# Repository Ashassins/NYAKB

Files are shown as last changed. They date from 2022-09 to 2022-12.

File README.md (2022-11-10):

# NYAKB: Not Your Average Keyboard
ECE 477 Project

NYAKB is a multimedia keyboard with hot swappable modules to enable flexibility for the users by allowing them to select the right keyboard layout for the task at hand. The product features a base keyboard with a familiar form factor, as well as modules which can be added and removed with a standard hot plug connector without interrupting the functionality of the rest of the keyboard. We will be making a display module and in the future other modules such as macropads, numpads, or rotary encoders could be added using the same connector to extend the functionality of the keyboard.

Project Website: https://engineering.purdue.edu/477grp3/

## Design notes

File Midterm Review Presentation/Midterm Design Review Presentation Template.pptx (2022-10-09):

## ECE477 Midterm Design Review: Team 3

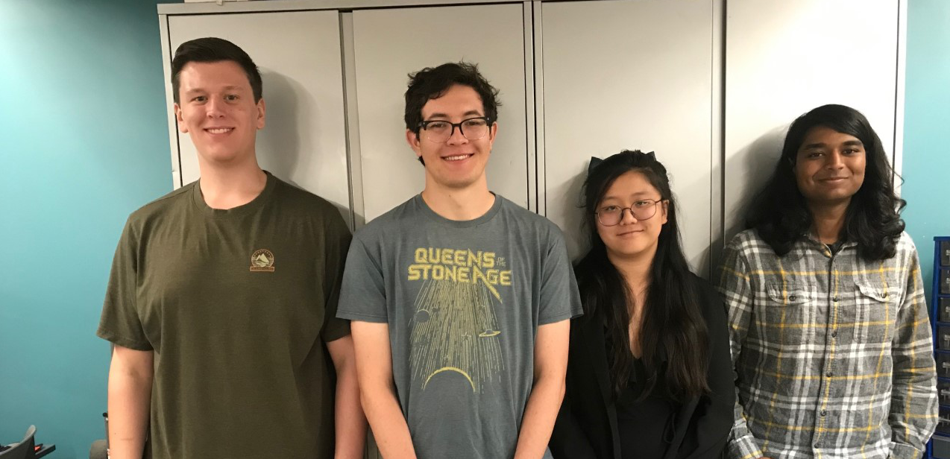
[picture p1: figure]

<Add team picture or relevant project picture here>

## Outline

- Project Overview
- Major Components
- Block Diagram
- Packaging Design
- Electrical Schematic
- PCB Layout
- Prototyping Progress
- Software Development Status
- Project Timeline
- Questions

## Project Overview

- Not your average Keyboard (NYAKB)

- NYAKB is a newcomer in the growing mechanical keyboard community that includes a high quality, phone sized LCD screen that will display various information, and can interact with the keyboard itself. The module will be detachable. Current keyboards on the market don't have the unique display functionality NYAKB has.

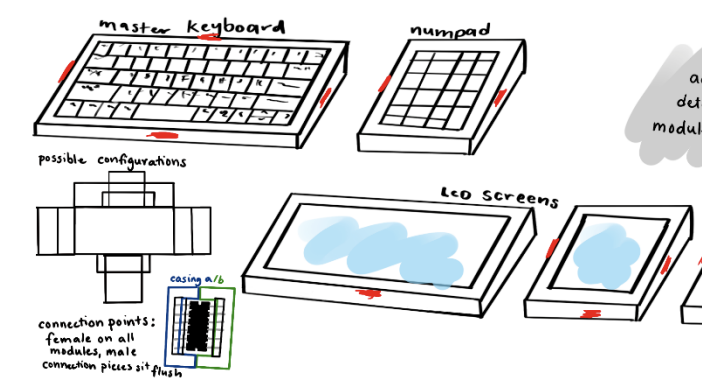
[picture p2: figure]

## PSSCs

1. PSSC #1 (Hardware): An ability to have a key switch matrix for the various typing keys on a keyboard that can be scanned and debounced for clean inputs by the microcontroller on the main keyboard module.
2. PSSC #2 (Hardware): An ability to drive an LCD display via SPI.
3. PSSC #3 (Hardware): An ability to step down 5V USB input power to 3.3V for the main keyboard MCU and display module MCU/display.
4. PSSC #4 (Hardware): An ability to have the main keyboard MCU serve as master and communicate to submodule MCU as slave over I2C.
5. PSSC #5 (Hardware): An ability to communicate key presses from the user to the Host PC over a USB connection.

## Major Components

- SUBTITLE

- Choose the major (electrical) components being utilized by your design. For each component, provide a brief description of what it is, relevant specifications, and what it will do. Examples of major components include the microcontroller, motors, wireless interfaces, power converters and regulators. Examples of relevant specifications include operating speed (uC), number of I/O (uC), stall current (motors), operating voltage, and expected current consumption

## Major Components

- Power Regulation

- Buck Converter: TPS563231DRLT
- Specs:
  - Input range 4.5V-17V
  - Output 3.3V
  - Max Current 3A
- Usage:
  - This will be used to step down USB 5V input to 3.3V that will power the main keyboard (stm32f4) as well as submodules via the hotplug connection

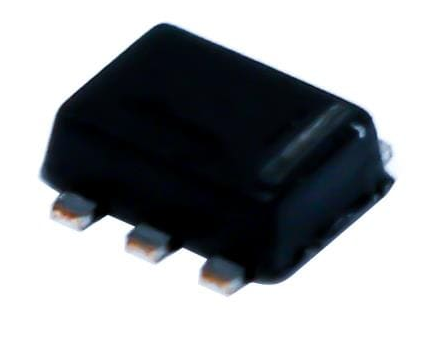
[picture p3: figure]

## Major Components

- Power Regulation

- Voltage Regulator: [Insert Name]
- Specs:
  - sdf
- Usage:
  - sdf

## Major Components

- Microcontrollers

- Main Keyboard MCU: STM32F407VGT6
- Specs:
  - USB FS Controller
  - I2C
  - GPIO
- Usage:
  - This MCU will be used to communicate with the host PC over USB and to submodules over I2C. It will also scan the key matrix with GPIO

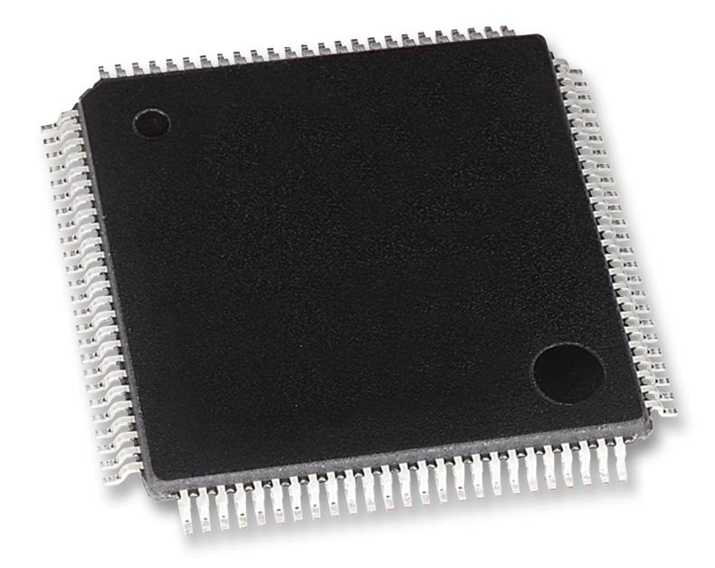
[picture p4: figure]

## Major Components

- Microcontrollers

- Main Keyboard MCU: STM32F091RCT6
- Specs:
  - I2C
  - SPI
- Usage:
  - This MCU will be used to communicate with the SPI TFT LCD display to draw info and to the main keyboard over I2C over the hotplug connector.

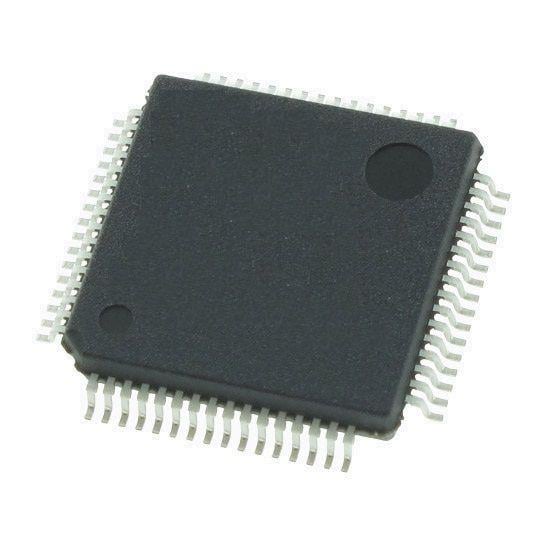
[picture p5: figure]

## Block Diagram

- Include one or more images of your system block diagram here. Block diagrams should include all relevant major parts and systems, bus widths, and interface types.

## Packaging Design

- Main Keyboard Original Design

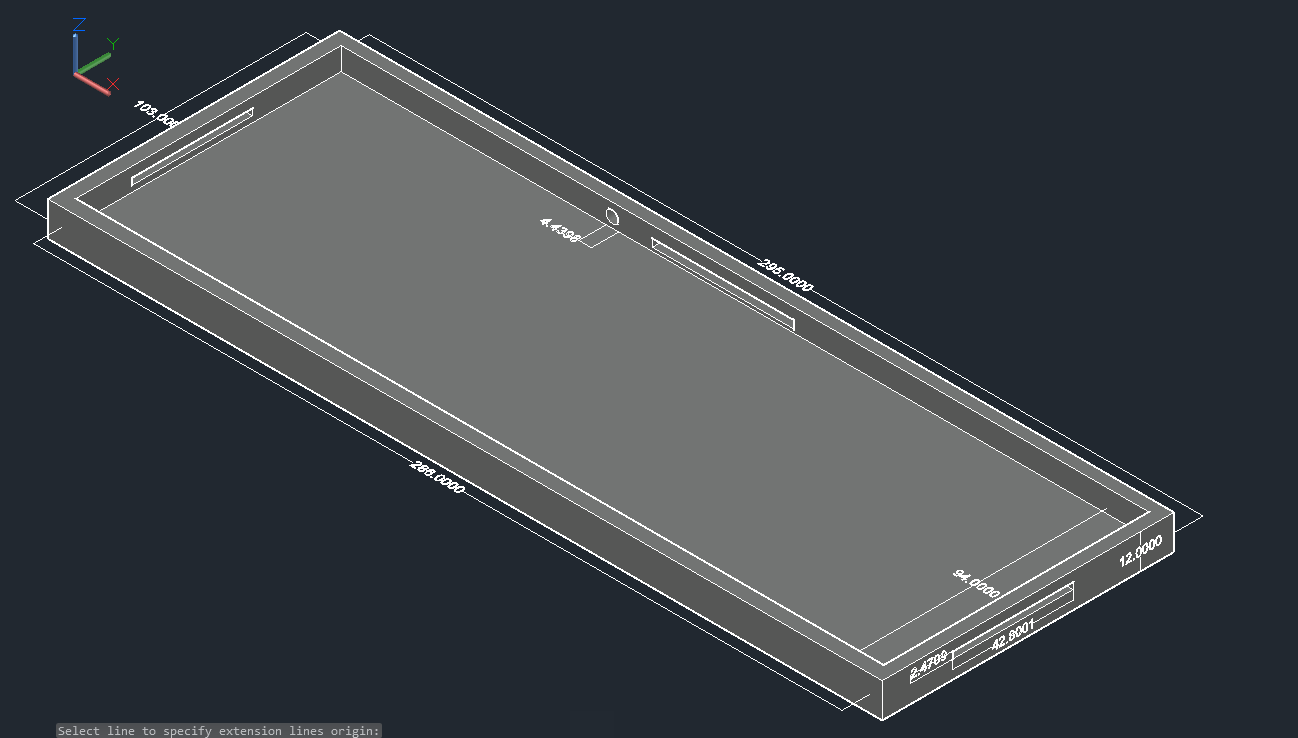
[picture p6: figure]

- Outer layer 295x103x12 mm
- Inner layer 286x94x8 mm
- 3 access points to allow it to connect to other modules, and a point of access to connect to the USB port.
- Keyboard has evolved, but the packaging design will remain fairly similar

## Packaging Design

- Peripheral Module

- Include one or more images of your packaging design here. Include relevant dimensions and how you are planning to manufacture your product packaging.
- We plan to use laser cut acrylic sheets to mount both keyboard modules

## Electrical Schematic

- Include one or more views of your electrical schematic here. If necessary, break up this section into multiple slides detailing various subsystems which are easily viewable (Hint: a zoomed out view of a large electrical schematic in which nothing can be read will not be helpful for the design review). Your schematics should be complete, organized, and readable.

## PCB Layout

- Include one or more views of your PCB Layout here. If necessary, break up this section into multiple slides detailing various subsystems which are easily viewable (Hint: a zoomed out view of a large electrical schematic in which nothing can be read will not be helpful for the design review). Your layout should be complete, organized, and readable.

## Prototyping Progress

- Describe your team’s prototyping progress here. For each of your project’s major components, what has been tested? What is known to work? What still needs to be tested, and what still needs to be proven to work?

## Software Development Status

- In this section, detail team progress with software development. List out the major modules for your team’s software. For each module, detail its status (Not yet started / In development / In testing / Completed)
- Keyboard Scanning and Debouncing (In development)

## Project Timeline

- Provide a timeline (or GANTT chart, etc.), starting from the current week until the end of the semester, detailing work to be undertaken in completing your team’s project.

## 3D Printing

- Questions?

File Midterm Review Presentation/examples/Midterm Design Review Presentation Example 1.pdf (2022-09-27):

# ECE 477 DESIGN REVIEW TEAM 3 − SPRING

2015

Garrett
Bernichon

Bryan
Marquet

John
Skubic

Tim
Trippel

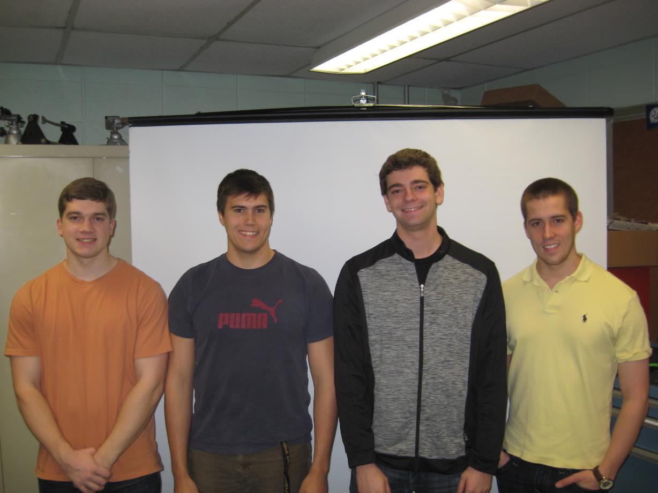
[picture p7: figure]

# OUTLINE

•Project overview

•Project-specific success criteria

•Block diagram

•Component selection rationale

•Schematic and theory of operation

•PCB layout

•Packaging design

•Software design/development status

•Project completion timeline

•Questions / discussion

# PROJECT OVERVIEW

•Stratus provides additional storage for mobile devices

•The storage is accessed from a Wi-Fi hotspot

•Data is stored on Stratus via a micro SD card

•System status is presented via a graphical display

•Stratus is powered by a lithium polymer battery chargeable by a USB cable

# PROJECT-SPECIFIC SUCCESS CRITERIA

•An ability to stream information from Stratus to an external device using Wi-Fi.

•An ability to charge and manage a battery system, and inform the microcontroller of remaining charge.

•An ability to read and write data to a SD card unit connected to Stratus.

•An ability to browse and select files to stream from Stratus via a mobile app.

•An ability to display information such as battery life, Wi-Fi connection status, and name of current file being accessed to the user via a graphics display connected to Stratus.

# BLOCK DIAGRAM

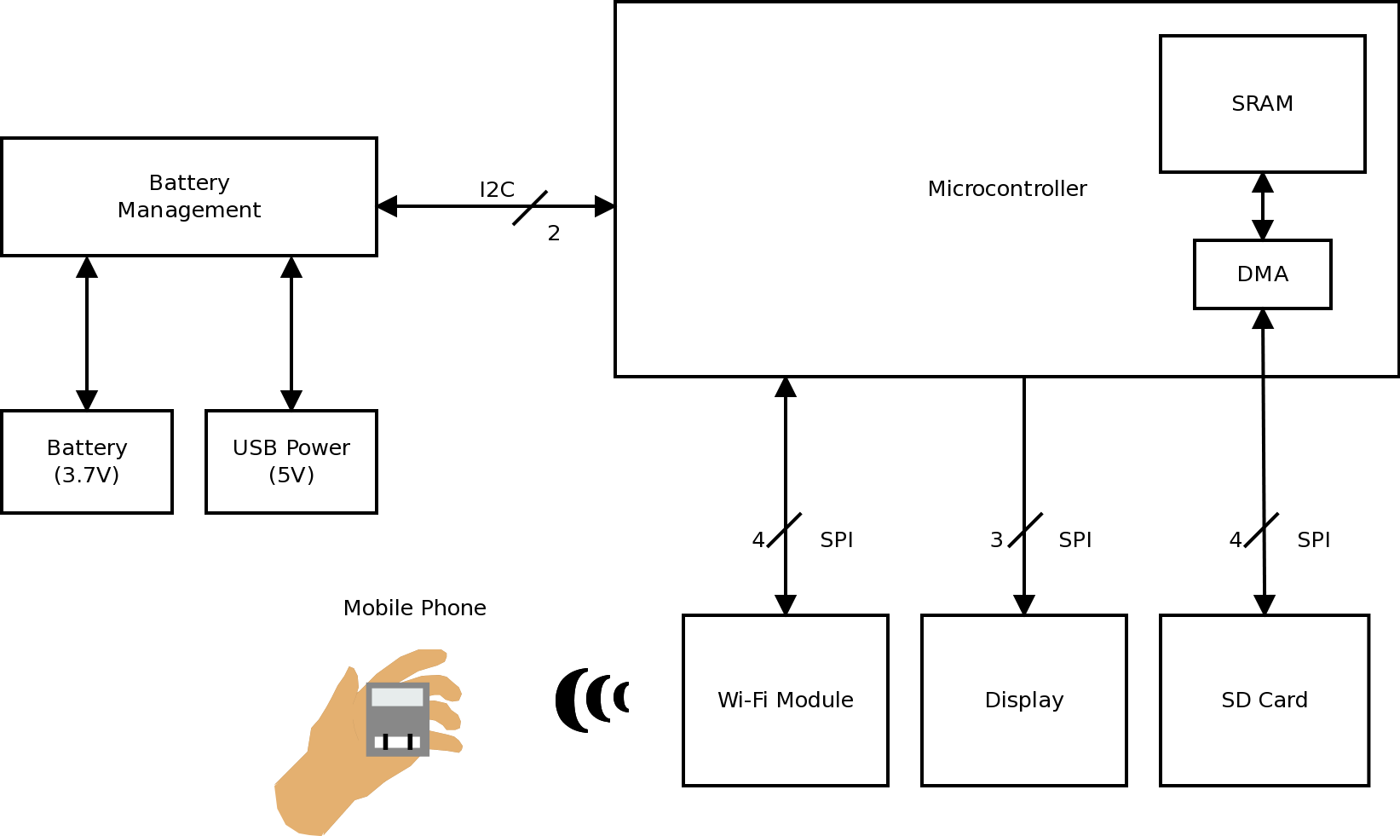
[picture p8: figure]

# COMPONENT SELECTION RATIONALE: MICROCONTROLLER

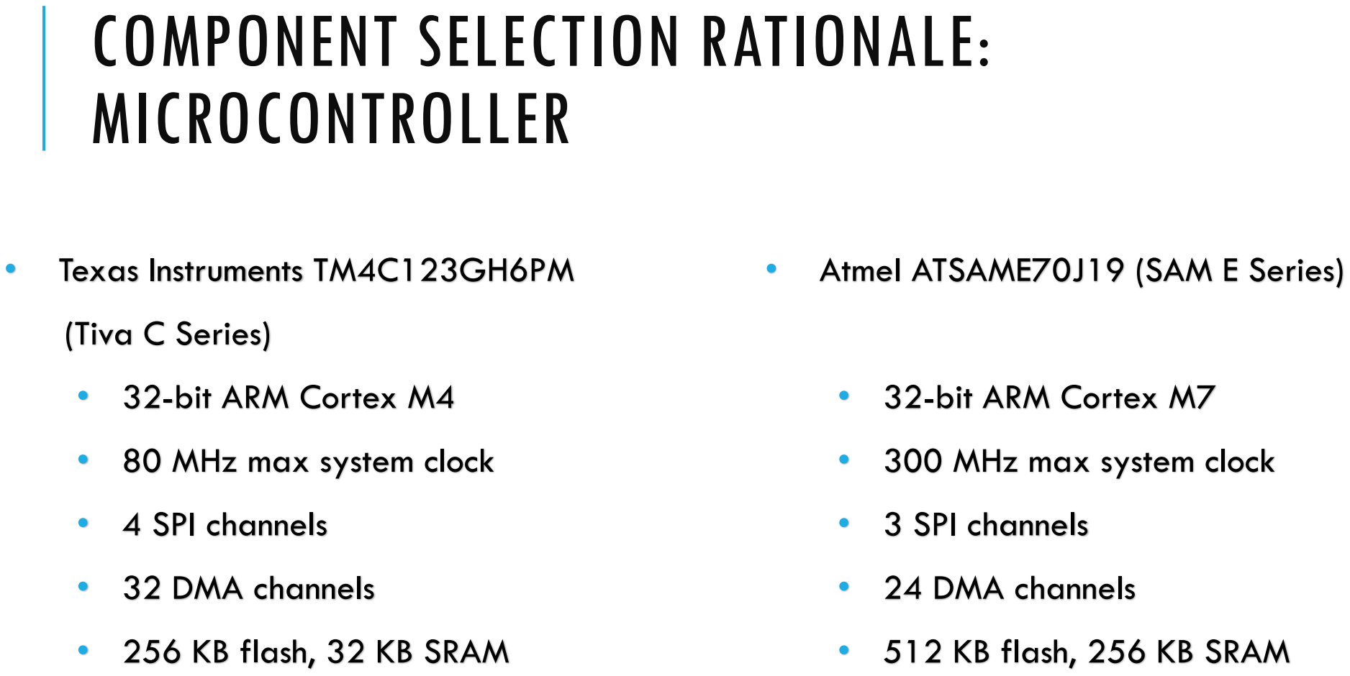
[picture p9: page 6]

- Texas Instruments TM4C123GH6PM

(Tiva C Series)

- 32-bit ARM Cortex M4
- 80 MHz max system clock
- 4 SPI channels
- 32 DMA channels
- 256 KB flash, 32 KB SRAM
- Atmel ATSAME70J19 (SAM E Series)
- 32-bit ARM Cortex M7
- 300 MHz max system clock
- 3 SPI channels
- 24 DMA channels
- 512 KB flash, 256 KB SRAM

# COMPONENT SELECTION RATIONALE: WI-FI VS. BLUETOOTH

### Wi-Fi

+ Higher throughput
+ More open
- Power Consumption
- Extra software for configuration as both an access-point or not

### Bluetooth

+ Low-power
- Low throughput

# COMPONENT SELECTION RATIONALE: WI-FI MODULE

TI CC3100

+ Creates a Wi-Fi hotspot
- Module has pins on bottom

TI CC3000

+ small module with antenna
- Can’t create a Wi-Fi hotspot

TI CC3200

+ Has built-in ARM processor + Creates Wi-Fi hotpot
- Requires an OS
- Not hand solderable

# COMPONENT SELECTION RATIONALE: DISPLAY

Sharp LS013B4DN04 LCD E-Paper hybrid

1.35” screen
+ Low power consumption
+ No external circuit needed
- More complex software

RePaper E-Paper display

1.3” screen
+ Low power consumption
+ Simple software interface
- Requires large external circuit
- Requires 3.3V and 5.0V

# COMPONENT SELECTION RATIONALE: BATTERY

Constraints:
- Maximum size, must fit inside packaging
- Minimum capacity, aiming for six hours of heavy usage (heavy = 370 mA approx.)

Decision:

- Polymer Lithium Ion Battery 2000 mAh

# SCHEMATIC/THEORY OF OPERATION : MICROCONTROLLER

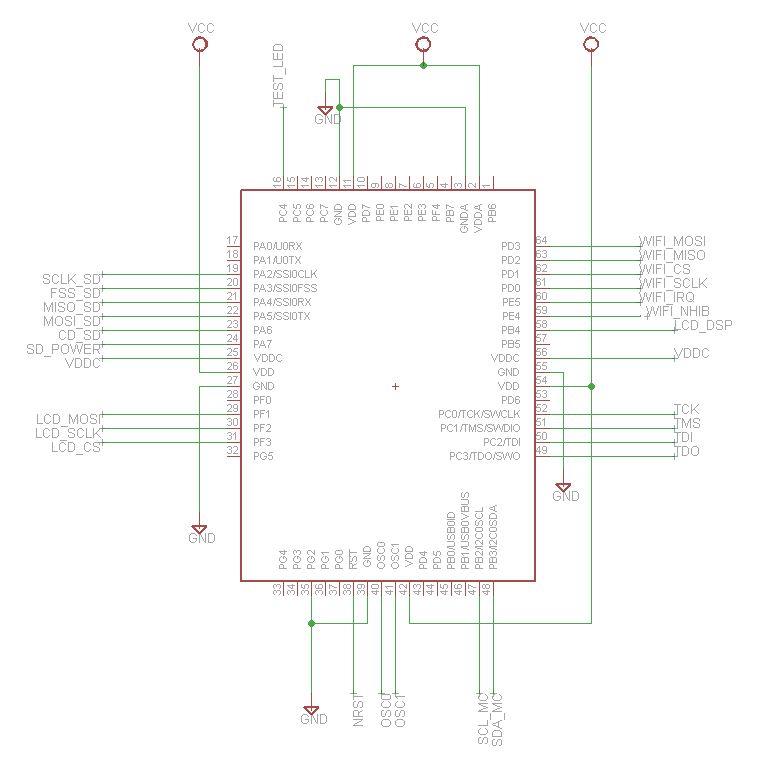
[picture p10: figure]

Microcontroller
- System Clock
- Internal PLL to achieve 40 MHz
- 16 MHz External (for boot-up)
- Serial connections
- Battery Monitor (I2C)
- SD Card (SPI)
- Wi-Fi module (SPI)
- LCD (SPI)

# SCHEMATIC/THEORY OF OPERATION : WI-FI

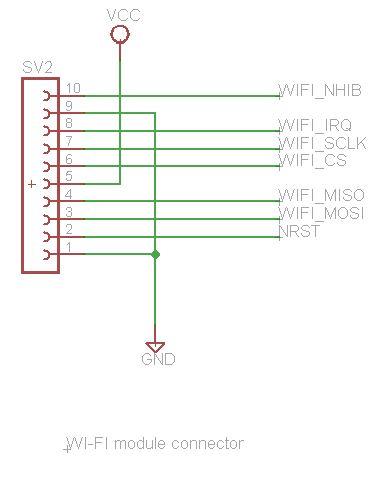
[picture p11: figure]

Wi-Fi Module
- External module
- 20 MHz max SPI CLK

Designing our own module
- Solderablility
- Antenna design

# SCHEMATIC/THEORY OF OPERATION : LCD

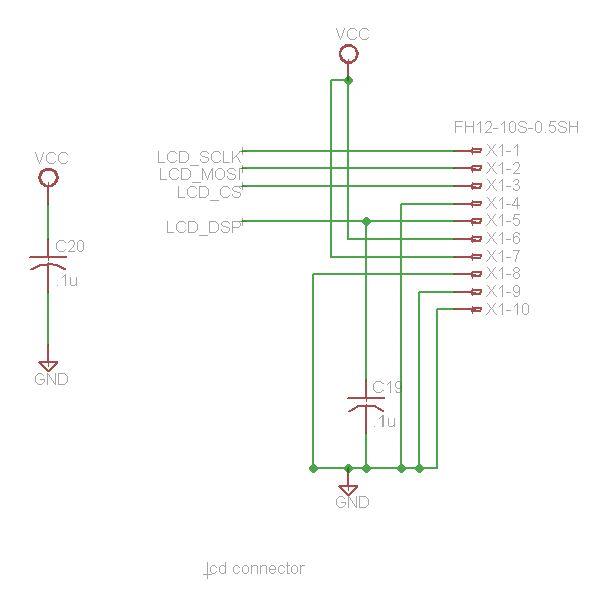
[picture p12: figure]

LCD/E-paper Hybrid Screen

•Interfaces with SPI at 1Mbps

•Setup so VCOM signal is set using SPI

# SCHEMATIC/THEORY OF OPERATION : SD CARD

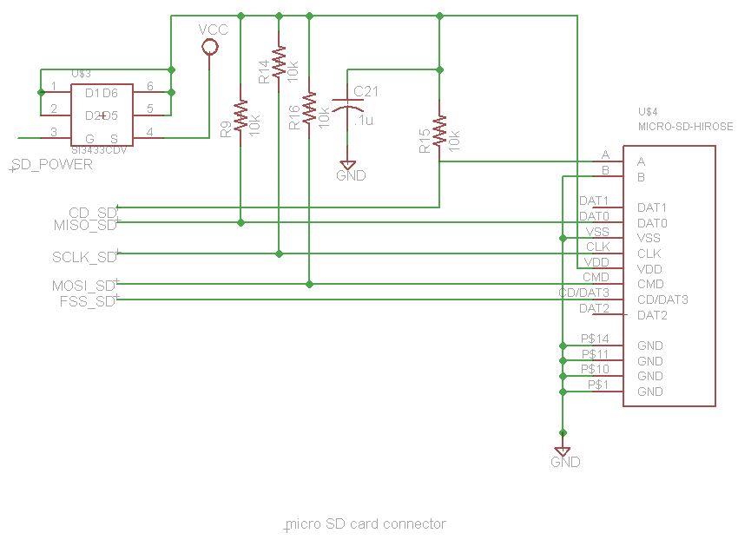
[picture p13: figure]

SD Card

•Interfaces with SPI at ~20-25 Mbps

•Pull-Up resistors for idle (Hi-Z) lines → SD requires idle to be high

•Power MOSFET for software control of hard-reset

•Chip-Detect signal

# SCHEMATIC/THEORY OF OPERATION: POWER

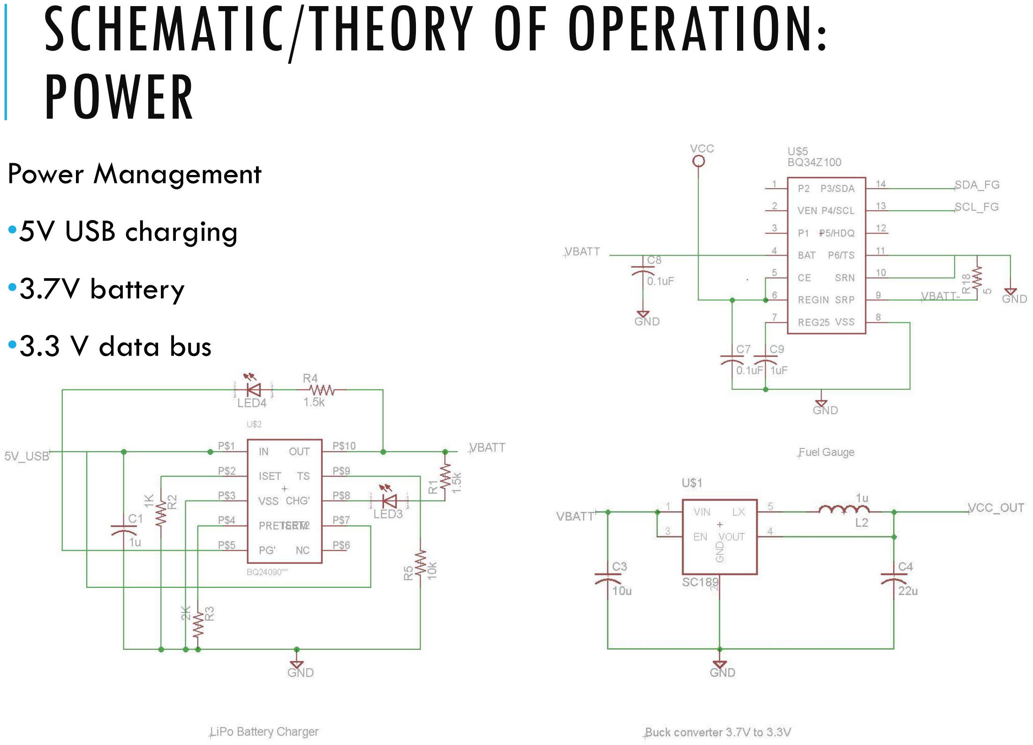
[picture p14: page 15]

Power Management

•5V USB charging

•3.7V battery

•3.3 V data bus

# PCB LAYOUT

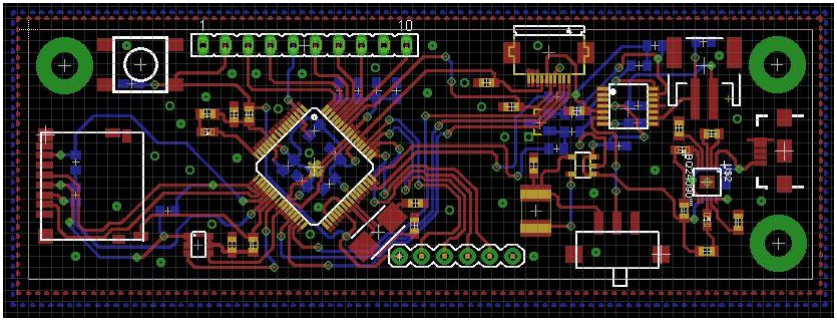
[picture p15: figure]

# PCB LAYOUT

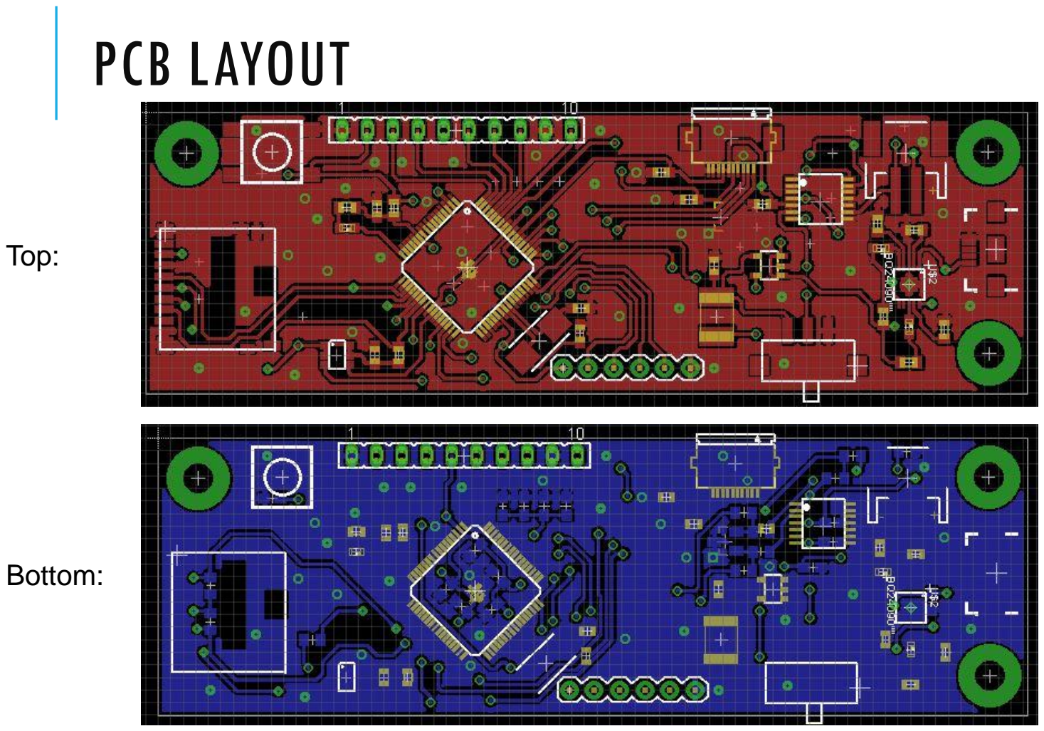
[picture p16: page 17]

Top:

Bottom:

# PCB LAYOUT

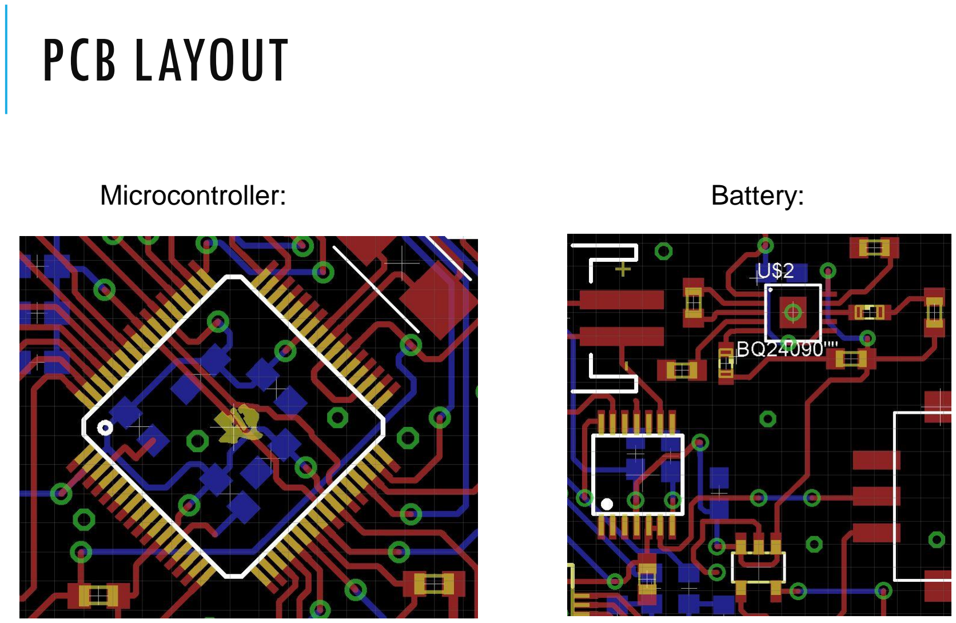
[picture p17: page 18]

Microcontroller: | Battery:

# PACKAGING DESIGN

•Dimensions: 90 x 57 x 13 (mm)

•Two 3D printed plastic pieces will be screwed together, one top and one bottom with sides

•Insulation will be added inside to aid in securing components.

•Battery Dimensions: 5.8 x 54 x 60 (mm)

•PCB Dimensions: 86 x 28 (mm)

# PACKAGING DESIGN

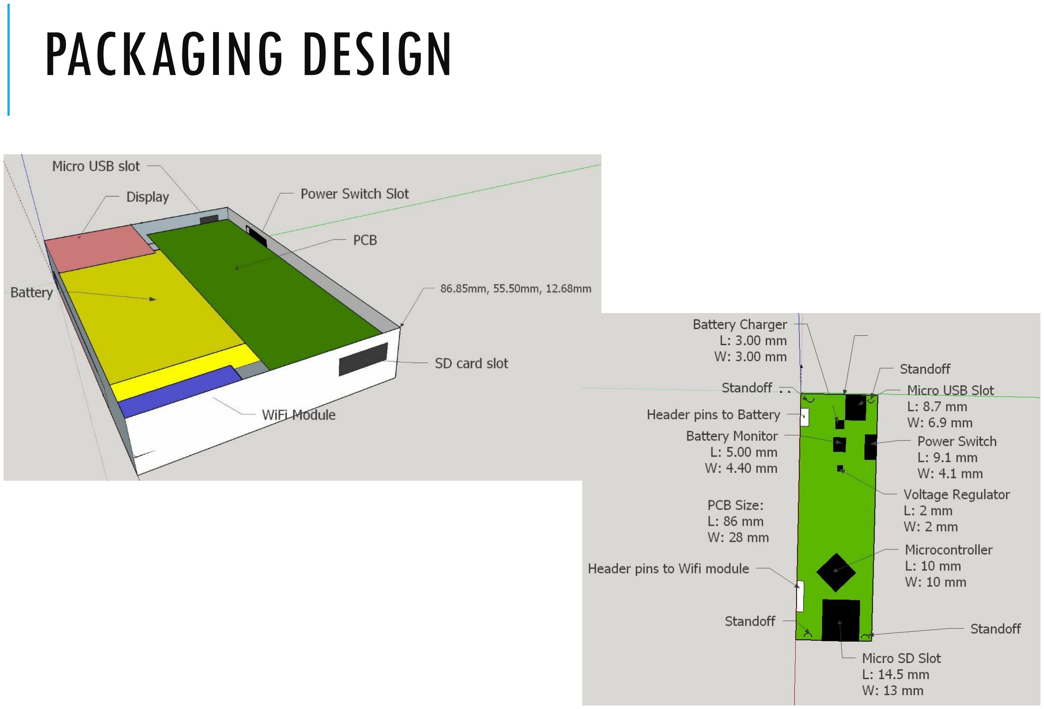
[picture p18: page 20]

# SOFTWARE DEVELOPMENT STATUS

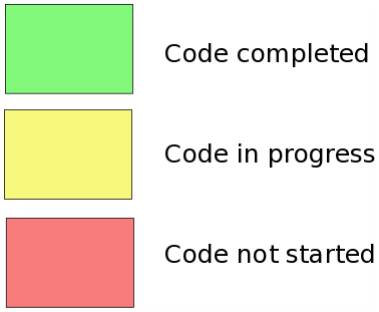
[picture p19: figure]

Embedded
- Embedded Initializations
- System Status Interrupts
- Wi-Fi Interface
- DMA Controller Interrupts
- Main Control Loop

iOS Development
- Using Python TCP server to act as Stratus
- Can request and receive music library
- Can request, receive, and play a song
- User Interface is 75% complete

# SOFTWARE DEVELOPMENT STATUS

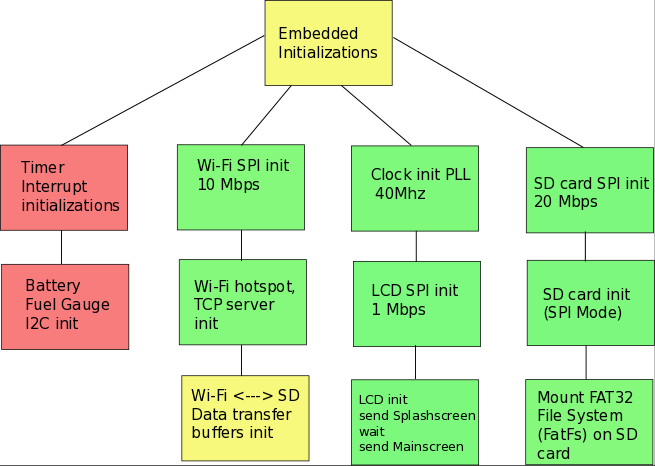
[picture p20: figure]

# SOFTWARE DEVELOPMENT STATUS

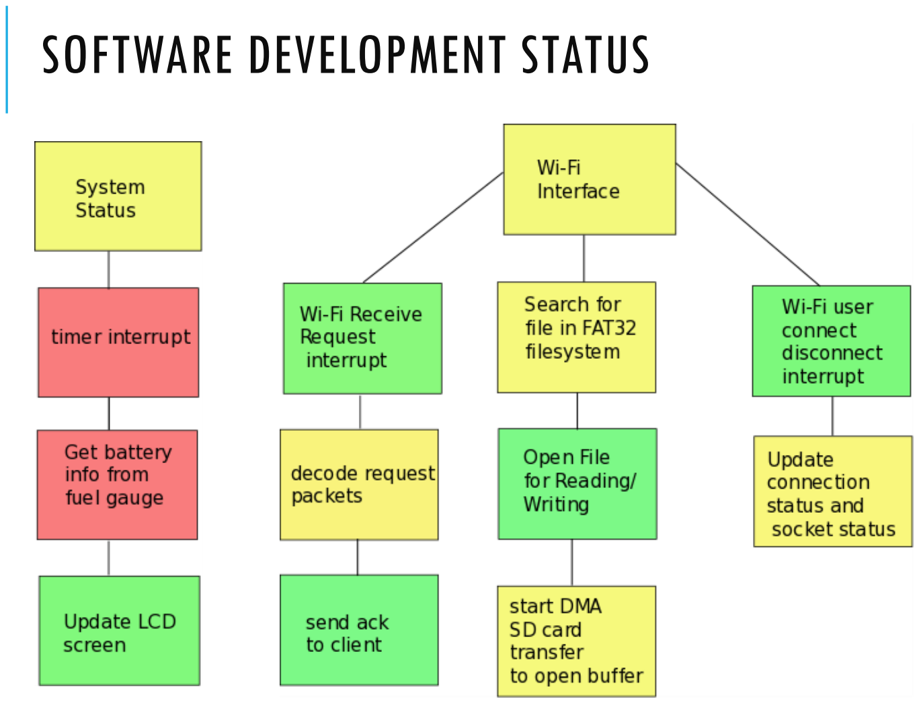
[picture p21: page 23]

# SOFTWARE DEVELOPMENT STATUS

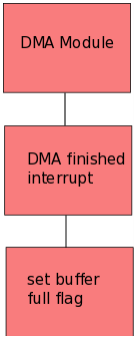
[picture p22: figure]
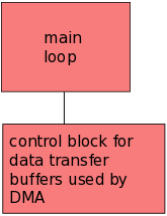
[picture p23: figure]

# SOFTWARE DEVELOPMENT STATUS

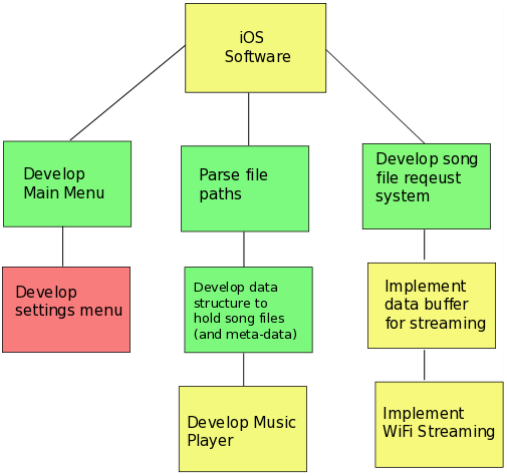
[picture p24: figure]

# PROJECT COMPLETION TIMELINE

Week 8: | finalize board
Week 9: | finish embedded initializations, finish iOS application, design own Wi-Fi module, battery communication
Week 10: | spring break
Week 11: | solder PCB components, Wi-Fi module interface, optimize file access (DMA)
Week 12: | integrate all software components
Week 13: | 3D print packaging, continue integration & testing
Week 14: | continue integration & testing
Week 15: | testing
Week 16: | showcase week

# QUESTIONS?

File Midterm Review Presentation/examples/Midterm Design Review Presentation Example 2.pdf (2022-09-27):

# ECE 477 DESIGN REVIEW TEAM 4 − SPRING 2015


Matt Carpenter, Grant Gumina, Chris Holly, and Michael Pak

## OUTLINE

### - Project overview - Project-specific success criteria - Block diagram - Component selection rationale - Packaging design - Schematic and theory of operation - PCB layout - Software design/development status - Project completion timeline - Questions / discussion

## PROJECT OVERVIEW

- A system which allows the user to draw and manipulate

objects in a virtual environment

- Utilizes a pen whose location in the 3D workspace is

known to provide an intuitive, natural interface

- Environment can be viewed and settings modified

remotely through a web interface

## PROJECT-SPECIFIC SUCCESS CRITERIA

- An ability to remotely view the canvas as well as analytical data using a web or mobile interface.
- An ability to identify and communicate to the user (using some form of haptic feedback mechanism) when the stylus is in close proximity to a previously drawn object.
- An ability to assist the user in drawing straight lines and other primitive shapes using smoothing algorithms.
- An ability to determine the location of a point in 3D space based on wireless signal strength as measured from multiple locations.
- An ability to maintain reasonable (percentage TBD) accuracy locating the stylus regardless of its orientation.

## BLOCK DIAGRAM


## COMPONENT SELECTION:

## MICROCONTROLLER

- Selection Criteria:
- Performance
- Community support and software tools
- Power consumption


- Considerations: ATmega328p, TI MSP430, and

PIC24FJ256DA206-I/PT

- Final Decision: ATmega328p for strong community

## COMPONENT SELECTION: CENTRAL COMPUTING DEVICE


- Selection based on Cost and amount of I/O
- Decision between Beaglebone Black, Raspberry Pi, and

Hummingboard

- Raspberry Pi was overall winner

## COMPONENT SELECTION: RF MODULE

- Requirements
- Operate in the unlicensed 433-444 MHz band
- Release and experience minimal interference from system
- Support RSSI (Received Signal Strength Indicator)
- Final Selection:
- Link TRM-433 Transceiver IC

## COMPONENT SELECTION: ORIENTATION SENSOR

- Inertial Measurement Unit
- Combines Accelerometer, Compass, Gyroscope
- Allows device orientation to be determined with reasonable

accuracy

- Contenders: Razor IMU & Sensor Stick
- Sensor Stick similarly equipped while being smaller, less

expensive

## PACKAGING DESIGN - STYLUS

Two piece, 3D printed construction comprised of outer body and inner core to which PCBs are attached

- Modular
- Inexpensive to manufacture
- Easy to swap in different grip designs for testing

## PACKAGING DESIGN - STYLUS


## PACKAGING DESIGN: MAIN BOARD & RECEIVERS

- Main Board:
- Simple combination of two sheets of Polycarbonate/Acrylic with

board attached in the middle to protect it from damage

- Receivers:
- Dependent on results of experiments once boards have been

produced and assembled

## SCHEMATIC/THEORY OF OPERATION: STYLUS


## SCHEMATIC/THEORY OF OPERATION: RECEIVER


## SCHEMATIC/THEORY OF OPERATION: MAIN BOARD – POWER CIRCUIT


## SCHEMATIC/THEORY OF OPERATION: MAIN BOARD - CONNECTIVITY


## SCHEMATIC/THEORY OF OPERATION: MAIN BOARD


## PCB LAYOUT – STYLUS


## PCB LAYOUT – RECEIVER


## PCB LAYOUT – MAIN BOARD


## SOFTWARE DEVELOPMENT STATUS: RASPBERRY PI ENVIRONMENT

- Camera Location: In Progress
- Object Drawing
- Single Point Objects: COMPLETE
- Double Point Objects: In Progress
- Intersection Detection: COMPLETE
- Save/Load: Future

## SOFTWARE DEVELOPMENT STATUS: RASPBERRY PI INTERFACE

- Coordinate Input (UART)
- Determine Transmission Standards: In Progress
- Convert Raw Signal to Float: COMPLETE
- Button Input (GPIO): In Progress
- Haptic Feedback (GPIO): In Progress

## SOFTWARE DEVELOPMENT STATUS: MICROCONTROLLER

- Process RSSI Input (SPI): In Progress
- Transmit Coordinates (UART): COMPLETE
- Process IMU Input (I²C): Future
- Compute Coordinates: In Progress
- Smooth Coordinates: Future

## PROJECT COMPLETION TIMELINE


Projection Completion Goal: 3rd week of April

## QUESTIONS?

## SOFTWARE: TESTING STILL TO BE DONE

- Camera Alignment
- Dual Point Object Drawing
- Saving/Loading Objects
- GPIO (Button) Input
- Haptic Feedback
- Computing/Smoothing Coordinates
- Processing IMU Input

## RASPBERRY PI SOFTWARE LAYOUT


## RASPBERRY PI SOFTWARE PROGRESS


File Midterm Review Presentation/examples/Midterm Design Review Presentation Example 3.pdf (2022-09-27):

# ECE 477 Design Review

## Team15 – Social Lock

### Team


### System Block Diagram

MSP430 uC; Deadbolt motor H-bridge; BLE112 Bluetooth module; Base station; Client Phone 1; Client; Phone N; UART; Parallel; Power; Credential server; HTTP

### PSSCs

1. An ability to securely determine whether a given mobile device is authorized to unlock the door.
2. An ability to mechanically displace the deadbolt to unlock and relock the door.
3. An ability to monitor the battery state and indicate a low battery condition to the user.
4. An ability to grant and revoke access to additional smartphones without either being physically present at the lock.
5. An ability to use grant temporary access to additional smartphones which expires automatically at the appointed time.

### Component Selection Rationale

Microcontroller
Bluetooth Module
H Bridge
LDO Regulator
Battery Monitor

### Microcontroller

TI MSP430F6659


Strong Community
Powerful
Our team is familiar
with the tools

### Bluetooth Module

Bluegiga BLE112

Built in
microcontroller
UART
Programmable
Well-supported

### H Bridge

Toshiba TB6593FNG


Low minimum motor
supply voltage (< 3V)
Low ambient current
draw
High current capacity
(1.2A)
Analog control

### LDO Regulator

Microchip Technology MCP1700T


Simple, 3 pin package
Max power consumption:
~150mW
Sleep power
consumption: ~15 uW

### Battery Monitor

Maxim 6775XKA+T

Low, 0.87uA current draw
1% Accuracy
Only need to indicate low
battery warning

Simpler than coulomb counter

### Packaging Design


3D printed box that
fits over deadbolt
Does not require any
tools to install
Removable adhesive
affixes device to
door

### Schematic/Theory of Operation


Schematic broken
into blocks
Each block covered
in following slides


### Power Block

Battery leads
LDO regulator
Battery monitor
Power switch


### Bluetooth Block

BLE112A module
Decoupling caps
uC UART
Debug UART

### Bluetooth Debug Block

10-pin JTAG
nRST switch
Vcc sense (not
supply)

### Grounds Block

Fake resistors
Connect AGND,
PGND to GND


### Motor Block H-bridge


Decoupling caps
uC control
20

-SSOP, 5 pins
Unregulated VBATT
for motor

### uC Debug Block

14

-pin JTAG
nRST shared with
debugger
Backchannel UART
Power source
selection


### HW Debug Block

Power LED
Voltage test points


### LED Block

Output LEDs for uC


### Switch Block

Input switches for uC

### uC Block

Isolated 8 MHz
crystal
Decoupling caps
Signal lines to
everything else


### PCB Layout – 1.65”x3.95”


### Power Layout

Power switch
Indicator LED
Back

-voltage
protection via
Schottky diode

### Motor Layout

Pins inconveniently
configured
Most vias per pin of
all components
PGND connected to
GND at R4
uC at right


### JTAG

### -14 Layout

Most difficult routing
Originally farther
from uC
Solution: signals
from left on top;
from right, bottom


### Jumper Layout

Allows selection of
uC UART path
Includes adjacent
nRST switches


### Oscillator Layout

Analog circuit
Isolated analog
ground plane
Equal

-length load
capacitor traces

### Switch & LED Layout

8-bit I/O for
debugging
Switches include
PU/PD resistors for
safety


### uC Layout

Decoupling caps on
bottom layer

### Bluetooth Layout

Signal planes
restricted near
antenna
Chip near corner for
minimal EMI
Debug UART header

### Software Structure and Status


### Software Structure and Status

### Software Structure and Status

- iOS App: Complete
- Parse Backend: Complete
- Base Station: Complete
- Bluetooth Chip: In Progress
- MSP430: In Progress


### Project Completion Timeline

Questions?

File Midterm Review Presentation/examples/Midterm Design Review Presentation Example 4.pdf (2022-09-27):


### Colin Graber

### Jason Kohl

### Jacob Varnau

### Cameron Young

# ECE 477 Design Review Team 2 - Spring 2015

R.I.S.K.

# Outline

### - Project overview - Project-specific success criteria - Block diagram - Component selection rationale - Packaging design - Schematic and theory of operation - PCB layout - Software design/development status - Project completion timeline - Questions / discussion

# Project Overview

### - Electronic implementation of the board game RISK - Game state information will be displayed via LED displays - Cards will be managed via a mobile web app - Goal: improve ease of setting up/playing game

# Project-Specific Success Criteria

1. An ability to keep track of the game state, such as troop numbers, country ownership, and battle information.
2. An ability to display troop counts and country ownership to the players via LEDs, 7-segment displays, and an LCD screen.
3. An ability to modify game state based on user input.
4. An ability to coordinate the distribution, display, and usage of Country Cards via a mobile web app.
5. An ability to collect statistical data related to
gameplay and to compute and display statistics about gameplay and random events.

# Block Diagram

Microcontroller (PIC32MZEC); Country 41 Country 0; Raspberry Pi SPI; (Web Server); Phones / Tablets; WiFi; 2 Push Buttons; Dice Display; LCD Display; Card Value; SPI; Rotary Encoder; 5 Pins; 3-wire; 4-wire

ON/OFF Switch

Continent
Bonus
Double Buffered Shift Registers
(Daisy-chained)

# Component Selection

### ●Microcontroller: PIC32MZ2048ECM064

- 50 Mb/s SPI modules
- Powerful enough for our needs
Family | Part | Clock | RAM | Pins | Cost
PIC32MZEC | PIC32MZ 2048M064 | 200 MHz | 512 kB | 64 | $13.52
PIC24 | PIC24FJ25 6DA206 | 16 MIPS | 98 kB | 64 | $7.15

# Component Selection

### ●Web Server: Raspberry Pi

- Easy-to-use WiFi adapter
| Shows Card Type | Shows Countries | Card Privacy | Hardware Required
LED | Yes | No | No | Lots
LCD | Yes | Yes | No | Some
Web App | Yes | Yes | Yes | Minimal

# Component Selection

### ●Shift Registers: 74HC595D

- Most bits we could find for reasonable cost
- Easy to daisy chain
- Has separate clocks for shifting data and latching it to output pins
- Surface mount to save board space

### ●Original Idea: I2C

- Each country would have its own address
- Too complex to be feasible

# Component Selection

### ●LCD Display: Gravitech 20x4 LCD

- Enough space for relevant game information
- Uses very common HD44780 controller

### ●Original Idea: 16x2 LCD

- Readily available
- Not enough space to describe game actions

# Packaging Design


●Frosted acrylic for top surface, opaque acrylic for others ●Rotary encoder and two buttons

# Country Schematic


# Country PCB (Components)


# Country PCB (Full)


# Main Board Schematic


# Main Board


# Layout

### ●Hardware drivers

- LCD and SPI drivers in development
- Main loop in design

### ●Game logic

- Complete

# Software Development

# Software Development


# Software Development


# Software Development

### ●Raspberry Pi

- Ad-hoc network setup complete
- SPI commands in development
- Must be master
- Websockets are in development

# Software Development

### ●Web app

- Graphics complete
- Webpage in development
- Submitting cards in development


# Project Timeline

### ●Week 8:

- Finalize Country PCB revisions, submit
- Finish Main PCB Schematic
- Start Main PCB Layout

### ●Week 9:

- Finish designing and order Main PCB
- Start Microcontroller IO (SPI) programming
- Continue Web app: fetch card info from Pi (server)

### ●Week 10 / 11:

- Solder parts onto country PCBs
- Connect Raspberry Pi and microcontroller over SPI

# Project Timeline

### - Week 12:

- Solder parts onto country PCBs
- Solder parts onto main PCB
- Pi / Web app: send cards successfully
- Micro: compute statistics
- Web App: display statistics

### ●Week 13 / 14 / 15:

- Debugging

### ●Week 16:

- Packaging

# Questions?

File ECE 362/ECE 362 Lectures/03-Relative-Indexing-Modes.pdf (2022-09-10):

# Cortex-M0 Instruction Set Relative & Indexed Addressing Modes

# ECE 362 https://engineering.purdue.edu/ece362/

© 2021, Rick. All Rights Reserved. Redistribution Prohibited.

# More reading

# - Textbook, Chapter 6, “Branch and Conditional

Execution”, pages 111 – 132.
– Talking about this in this lecture.

# - Textbook, Chapter 5, “Load and Store”, pages

97 – 110.
– Talking about this in the second half of the lecture.

# More reading after that

- Textbook, Chapter 7,”Structured Programming”, pages 133 – 160. – We’ll talk about this soon.
- Textbook, Chapter 8, “Subroutines”, pages 161 – 202.
– We’ll talk about this soon.

## - ARMv6-M Architecture Reference Manual (436 pages)

### – Get familiar with sections A5.2 (16-bit Thumb encoding) and A6.7 (Alphabetical list of ARMv6-M Thumb instructions)

# Instruction Synopsis

ADDS ADCS; SUBS SBCS RSBS; (NEGS); MULS; MVNS; ASRS; ANDS ORRS; BICS; EORS; LSLS; LSRS RORS; LDR; LDRH LDRSH; LDRB; STR; LDM; POP; STRH; STRB; STM; PUSH; CMP; CMN; TST; LDRSB; BKPT; WFE; WFI; SVC; NOP; MOVS; ADR; SXTB; SXTH; UXTB; UXTH; REV; REV16 REVSH; BLX; Arithmetic; Logical; Copy Values; Store; Load; Control Flow; Exceptions; Bcc

# Relative Addressing Mode

## - The CPU will fetch/execute instructions one after another. We need a way to tell the CPU to fetch its next instruction from a different address. That means changing the PC to a new value rather than

incrementing it.
- We can’t easily load a 32-bit value into a register.

## - Just as hard to jump. There is no jump instruction with absolute

addressing mode like we had with the simple computer or x86.
– Not enough room in a 16-bit instruction to store a 32-bit address.
– Instead, we have branches that are relative.

# The Relative Branch

- Effectively adding a signed immediate value (+/-) to the PC.
- Unconditional and conditional versions.

## - NOTE: During the execution of any instruction, the PC always points

to the next instruction.
– A branch to offset 0 would continue with the next instruction.
– This is true for every architecture I know of.

### – On ARM CPUs, a branch to offset 0 looks like this:

instr | instr | instr | B (0) | instr | instr | instr | instr | instr

Except ARM Cortex

# Branch normally used with a label

- We don’t have to care about ARM CPUs being strange.
- We don’t want to have to hand-compute address offsets… ever. – Let the assembler do it for us.

.text
.global main
main: movs r0, #5
movs r1, #1
L0: subs r0, #1
beq done
| b | L2
L1: | b | L0
done: | bkpt
L2: | lsls r1,r1,#1
| b | L1

0x2005
0x2101
0x3801
0xd000
0xe001
0xe7fb
0xbe00
0x0049
0xe74b

“Example 0” on lecture
notes web page

# Simpler Branch Example

## - Now that we can appreciate that the assembler will find branch offsets for us, let’s try a simple loop for an example:

.text
.global main
main:
movs r0, #5
movs r1, #0
loop:
adds r1, #1
subs r0, #1
bne loop
done: bkpt

“Example 1” on lecture
notes web page

# Longer Branch Range Is Better

## - There is a limit to how far forward and backward a branch instruction can

redirect execution.

## - If a program gets too long, it may not

be possible to branch to some part of it.

## - We usually want to maximize the range

of a branch instruction.

## – One way to do that is multiply the offset

encoded in the instruction by 2.

.text
L0: | movs r0, r2
| adds r0, r1
| subs r1, r2, r1
| bne L1
| // 1500 instrs.
| subs r1, r0, r2
| beq L0
| adds r1, #4
L1: | rsbs r1, r2, #0


B “PC-2”
11100 11111111111
0xE7FF

BNE “PC+12”
1101 0001 00000110
0xD106

Instructions always start
on an even address.
So multiply “imm” value
by 2 to get byte offset.

# How to use conditional branches

## - In years past, we used to go into tedious detail about how condition codes are set, and how branches interpret those codes. It’s simpler than that:

– Use an instruction that modifies or tests a value.
- When you want to compare two integers, that’s subtraction.
- An instruction that sets the flags has an ‘S’ suffix. (e.g. SUBS) – Use a branch that interprets the test in the way you want.
- Branches conditions are set up to work with subtraction.

# Branch Selection Example #1

# - Subtract R5 from R2 to give R6. (R6 = R2 - R5)

– I want to branch to error if R2 <= R5.
- In other words, if R6 is negative or zero.

## – I want to interpret all values as signed, 2’s complement

integer representation.

SUBS R6, R2, R5
BLE error

# Branch Selection Example #2

# - Subtract R5 from R2 to give R6. (R6 = R2 - R5)

– I want to branch to error if R2 <= R5.
- In other words, if R6 is negative or zero.

## – I want to interpret all values as unsigned, 2’s

complement integer representation.

SUBS R6, R2, R5
BLS error

# Branch Selection Example #3

- I don’t want to subtract anything.
– I want to branch to error if R2 | > | R5.
- In other words, if subtraction would be greater than zero.

## – I want to interpret all values as signed, 2’s complement

integer representation.

CMP | R2, R5
BGT | error
| | Wait. Why is it “CMP” rather than “CMPS”?

# Branch Selection Example #4

- I don’t want to subtract anything.
– I want to branch to error if R2 >= R5.
- In other words, if subtraction would be greater or equal to zero.

## – I want to interpret all values as unsigned, 2’s complement

integer representation.

CMP | R2, R5
BHI | error
BEQ | error

# Signed or Unsigned?

# - This only matters when you are working with very large integers. For instance: 0xffffffff

# – Is this a negative number?

## - It depends on whether we choose to interpret it as a

signed or unsigned number.

## - If we want to treat it as a signed integer, it is -1 - If we want to treat it as unsigned, it is 4,294,967,295

# Signed or Unsigned?

# - If we do math on numbers that we want to treat as unsigned, it means we need to change the

interpretation of “less than zero”.
– ADDS, SUBS, and CMP work the same either way.

# – The proper branch must be selected to reflect what

we want.

# Signed or Unsigned?

# - In C, we can explicitly declare variables that are never negative (always positive or zero) like this:

unsigned int | big32 = 0xffffffff; // AKA uint32_t
unsigned short big16 = 0xffff; | // AKA uint16_t
unsigned char big8 = 0xff; | // AKA uint8_t

# - We’ll look at this again when we talk about

converting C into assembly language.

# Logical Shift Left

- We can shift a 32-bit value in a register “left” by any number of bits.

### – This is the same as the C language operator: << – Bits that are shifted out the left end (MSB) of the register are moved into the

APSR Carry flag, so we call it “LSLS”.
– Zeros are shifted in on the right side (LSB).

Example: LSLS R0, R0, #3; APSR.C; (forgotten)

1 0 1 1 1 0 0 1 1 0 0 0 1 0 0 1 1 0 0 1 1 0 1 0 0 0 1 1 1 1 1 1

1 0 | 1 | 1 1 0 0 1 1 0 0 0 1 0 0 1 1 0 0 1 1 0 1 0 0 0 1 1 1 1 1 1 0 0 0

Initial R0

New R0

# We can use LSL to test bits

- Shift “leftmost” bit into the carry flag.

# - How do we test if the carry flag is set?

## – BCS: “Branch if Carry Set”

// Count the number of ‘1’ bits in R2.
// Store result in R0.
movs r0, #0
more: | lsls r2, r2, #1
| bcs one
| beq done
| b more
one: | adds r0, #1
| b more
done: | bkpt

“Example 2” on lecture
notes web page

“Couldn’t we have used this a few slides ago instead of BHI and BEQ?”
Yes! But you wouldn’t
have learned as much.

# Other Shift & Rotate Instructions

Logical Shift Right: LSRS R0, R0, #2

APSR.C; (forgotten)

1 0 1 1 1 0 0 1 1 0 0 0 1 0 0 1 1 0 0 1 1 0 1 0 0 0 1 1 1 1 1 1

0 0 1 0 1 1 1 0 0 1 1 0 0 0 1 0 0 1 1 0 0 1 1 0 1 0 0 0 1 1 1 1 | 1 | 1

Initial R0

New R0

Arithmetic Shift Right: ASRS R0, R0, #2

APSR.C; (forgotten)

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

1 1 1 0 1 1 1 0 0 1 1 0 0 0 1 0 0 1 1 0 0 1 1 0 1 0 0 0 1 1 1 1 | 1 | 1

Initial R0

New R0

Rotate Right: RORS R0, R0, #6

APSR.C

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

1 1 1 1 1 1 1 0 1 1 1 0 0 1 1 0 0 0 1 0 0 1 1 0 0 0 0 0 1 0 0 0 1

Initial R0

New R0

# Bitwise Logical Instructions

ANDS R0, R1
1 0 1 1 1 0 0 1 1 0 0 0 1 0 0 1 1 0 0 1 1 0 1 0 0 0 1 1 1 1 1 1

0 0 0 0 1 0 0 0 0 0 0 0 1 0 0 1 1 0 0 1 1 0 0 0 0 0 1 1 1 1 0 0

Initial R0
AND
R1
New R0

0 0 0 0 1 0 0 0 0 0 0 0 1 1 1 1 1 1 1 1 1 0 0 0 0 0 1 1 1 1 0 0

ORRS R0, R1
1 0 1 1 1 0 0 1 1 0 0 0 1 0 0 1 1 0 0 1 1 0 1 0 0 0 1 1 1 1 1 1

1 0 1 1 1 0 0 1 1 0 0 0 1 1 1 1 1 1 1 1 1 0 1 0 0 0 1 1 1 1 1 1

0 0 0 0 1 0 0 0 0 0 0 0 1 1 1 1 1 1 1 1 1 0 0 0 0 0 1 1 1 1 0 0

(mask)

(bits to set)

Initial R0
OR
R1
New R0
BICS R0, R1
1 0 1 1 1 0 0 1 1 0 0 0 1 0 0 1 1 0 0 1 1 0 1 0 0 0 1 1 1 1 1 1

1 0 1 1 0 0 0 1 1 0 0 0 0 0 0 0 0 0 0 0 0 0 1 0 0 0 0 0 0 0 1 1

0 0 0 0 1 0 0 0 0 0 0 0 1 1 1 1 1 1 1 1 1 0 0 0 0 0 1 1 1 1 0 0 (bits to clear)

Initial R0
AND NOT
R1
New R0

# Bitwise Logical Instructions

EORS R0, R1
1 0 1 1 1 0 0 1 1 0 0 0 1 0 0 1 1 0 0 1 1 0 1 0 0 0 1 1 1 1 1 1

1 0 1 1 0 0 0 1 1 0 0 0 0 1 1 0 0 1 1 0 0 0 1 0 0 0 0 0 0 0 1 1

Initial R0
AND
R1
New R0

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

MVNS R0, R1 // Also known as NOT
1 0 1 1 1 0 0 1 1 0 0 0 1 0 0 1 1 0 0 1 1 0 1 0 0 0 1 1 1 1 1 1

0 1 0 0 0 1 1 0 0 1 1 1 0 1 1 0 0 1 1 0 0 1 0 1 1 1 0 0 0 0 0 0

(bits to toggle)

Initial R1

New R0

# Loads and Stores Indirect/Indexed Address Mode

## - The Cortex-M0 CPU cannot reference memory with

arithmetic or logical instructions.

## - It can only reference memory with load and store

instructions.
– That’s why it’s called a load/store architecture.
- It also cannot refer to an absolute address.
– Instead, it refers to an address relative to a register value. – A branch is relative to the PC.
– A load or store is relative to one of registers R0 – R7.

# LDR: Load a word of memory into a register

- Let’s say R0 holds the value 0x20000000.

## - We want to load the four-byte value contained in addresses

0x20000000 – 0x20000003 into register R1.

## - This is the instruction:

– LDR R1, [R0]

## - “Use the value in R0 as an address. Read 4-bytes starting from that address, and put the result in R1.”

- Caveat: R0 must be evenly divisible by 4.
– If not, it will invoke a fault handler. You don’t want that.

# STR: Store register into a word of memory

- Let’s say R0 holds the value 0x20000000.

## - We want to store the four-byte value contained in R1 to the addresses

0x20000000 – 0x20000003.

## - This is the instruction:

– STR R1, [R0]

## - “Use the value in R0 as an address. Write the value of R1 into the 4-bytes starting at that address.”

- Caveat: R0 must be evenly divisible by 4.
– If not, it will invoke a fault handler. You don’t want that.

# Example of Store / Load

# - Consider the following program:

## ldr r0, =0x20000000 // R0 = 0x20000000

str r1, [r0] | // mem[0x20000000] = R1
ldr r1, [r0] | // R1 = mem[0x20000000]

# Simple Store/Load Example

# - In this example, we initialize R2 to an explicit address (which happens to be the lowest address

for SRAM on STM32).

.text
.global main
main:
movs r0, #5
movs r1, #0
ldr r2, =0x20000000
loop:
str r0, [r2]
adds r1, r0, #1
ldr r1, [r2]
subs r0, #1
bne loop
done: bkpt

“Example 3” on lecture
notes web page

# Another Store/Load Example

# - In this example, we initialize R2 to a label that refers to a location

where space is allocated.

# We don’t know where it gets put. The assembler decides for us!

.text
.global main
main:
movs r0, #5
movs r1, #0
ldr r2, =storage
loop:
str r0, [r2]
adds r1, r0, #1
ldr r1, [r2]
subs r0, #1
bne loop
done: bkpt

.data
storage: .word 0

“Example 4” on lecture
notes web page

# Indirect addressing

# - When you see [ ] around something, it means to treat

it as an address and do a memory operation.

## – We don’t need to only use R0 for an address. We can use

R0 – R7.

## – But we’ve seen in a past lecture that it’s hard work to

initialize a register to a 32-bit address.

## – Is there a way we can use LDR/STR to refer to memory near that address?

# Indexed Addressing Mode

## - LDR/STR take an extra offset or index - LDR R1, [R0, #12]

- “Take the value of R0, add 12 to it, use the sum as an address,

## go to that address, read four contiguous bytes, and put it in R1.”

- The offset can be any multiple of 4 from 0 – 124.
- Similar specification for STR.
- Caveat: R0+offset must be evenly divisible by 4.

# Indexing with a register

## - I know what you’re going to ask: “Can I index with a register instead of an immediate value?” - LDR R1, [R0, R2] “Take the value of R0, add it to the value of R2, use the sum as an address, read four contiguous bytes, and place them in R1.”

- Similar specification for STR.
- Caveat: R0+R2 must be evenly divisible by 4.

# Also byte/halfword load/store

- There are also
– STRH: store a halfword (2 bytes) [index is a reg or an #imm multiple of 2 from 0 – 62] – LDRH: load an unsigned halfword (2 bytes) [index is the same as STRH]
– LDRSH: load a signed halfword (sign-extend bit 15) [index must be a reg]
- Caveat: Halfword load/stores must use an address that is evenly divided by 2.

– STRB: store a byte [index is a reg or #imm from 0 – 31]
– LDRB: load an unsigned byte [index is the same as STRB]
– LDRSB: load a signed byte (sign-extend bit 7) [index must be a reg]
- A byte load or store has no alignment requirements.

# Why are there two kinds of loads?

- Why have LDRH / LDRSH and LDRB / LDRSB when we only have STRH and STRB?

LDR; LDRH LDRSH; LDRB; STR; STRH; STRB; LDRSB

- Registers are always treated as 32 bit values.
– There is no instruction to “add only the lower 16 bits of registers Rx and Ry”
- When loading an 8-bit value from memory, we need to know if it is supposed to be treated as signed or unsigned. (i.e., should bit 7 indicate it is negative)
– If we load 0xff from memory using LDRB, it will set the destination register to 0x000000ff – If we load 0xff from memory using LDRSB, it will set the destination register to 0xffffffff.

Store

Load

# Store Byte/Load Byte Example

# - R0 starts out as 0xfc - One byte is stored in

memory.

# - It is loaded from memory as a signed byte and

then incremented.

.text
.global main
main:
movs r0, #0xfc
ldr r2, =0x20000000
movs r3,#0
loop:
strb r0, [r2]
// must use reg index
ldrsb r0, [r2,r3]
adds r0, #1
bne | loop
done: | bkpt

“Example 5” on lecture
notes web page

# Reading and writing arrays

# - How can we implement the following C code:

int array1[100];
int array2[100];
…
for(n=0; n<100; n++)
array1[n] = array2[n] + 5;

.data
array1: .space 400
array2: .space 400

.text:
add5: | movs r0, #0 | // n = 0
check: cmp r0, #100 | // n < 100?
| bge done | // if not, done
lsls r3, r0, #2 // r3 = r0 * 4 ldr r4, [r2,r3] // array2[n]
| adds r4, #5 | // add 5
str r4, [r1,r3] // array1[n]
| adds r0, #1 | // n = n + 1
| b check | // again!
done: | b somewhere_else

For the next few minutes, assume that: n is just register R0,
R1 is magically the address for array1, R2 is magically the address for array2.

# How to load literal values

- We can jump (update the PC) to a relative offset from the current PC value.
- We can load a value from a relative offset from the current PC value.
- LDR R1, [PC, #12]
“Take the current PC value, round it up to a multiple of 4, add 12 to it, use it as an address, read 4 contiguous bytes from memory, and put the result in R1.”
- Can we store to an address relative to the PC?
– No. The PC normally points to read-only memory where the instructions are.
- Bonus: PC (rounded up) +12 is automatically evenly divisible by 4.
– But the data you refer to might not be. More on that in a bit.
- We almost always use the preferred form LDR R1, label
- Caveat: The item must be no further than 1020 bytes beyond the PC in the text segment.

# Example of literal load

.text
LDR R1, bigvalue
LDR R2, value2
ADDS R3, R1, R2
B somewhere

.balign 4
bigvalue: | .word 0xfedcba98
value2: | .word 0xdecaf123

Maximum offset: 1020 bytes. Word must be in the text segment. Instructions are 2 bytes long. Word must be 4-byte aligned. How do we guarantee alignment?

# Label is an address

# - What value is put into the memory words allocated for addr1 and addr2?

.data
array1: .space 400
array2: .space 400

.text
addr1: .word array1
addr2: .word array2
addr1 is the location in memory of a 4-byte reservation initialized to be the address of array1.

array1 is the location in memory
of a 400-byte reservation that is uninitialized. Maybe array1 is in the data segment.

Maybe addr1 is in the
text segment.

0x20000000
0x20000190

0x20000000
0x20000190

0x08000400
0x08000404

Values like this in the text segment are called a “literal pool”

# Reading and writing arrays

# - Consider this C code again:

int array1[100];
int array2[100];
…
for(n=0; n<100; n++)
array1[n] = array2[n] + 5;

ldr r1, addr1
ldr r2, addr2
add5: | movs r0, #0 | // n = 0
check: cmp r0, #100 | // n < 100?
| bge done | // if not, done
lsls r3, r0, #2 // r3 = r0 * 4 ldr r4, [r2,r3] // array2[n]
| adds r4, #5 | // add 5
str r4, [r1,r3] // array1[n]
| adds r0, #1 | // n = n + 1
| b check | // again!
done: | b somewhere_else
.balign 4
addr1: .word array1
addr2: .word array2

.data
array1: .space 400
array2: .space 400

# If that still seems like

too much work...

- Just use LDR with a =symbol,

## and it will automatically build a literal pool at the end of the block of code…

ldr r1, =array1
ldr r2, =array2
add5: | movs r0, #0 | // n = 0
check: cmp r0, #100 | // n < 100?
| bge done | // if not, done
lsls r3, r0, #2 // r3 = r0 * 4 ldr r4, [r2,r3] // array2[n]
| adds r4, #5 | // add 5
str r4, [r1,r3] // array1[n]
| adds r0, #1 | // n = n + 1
| b check | // again!
done: | b somewhere_else

.data
array1: .space 400
array2: .space 400

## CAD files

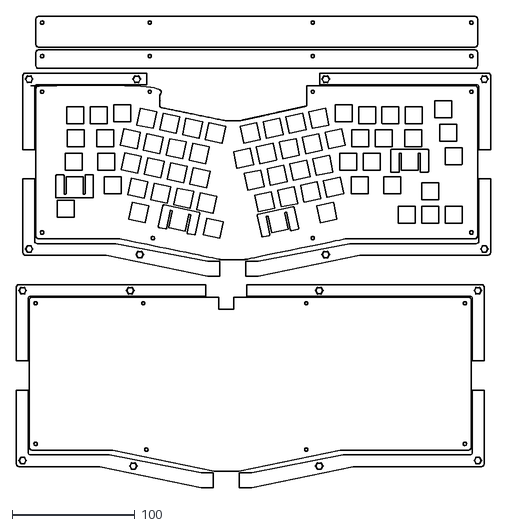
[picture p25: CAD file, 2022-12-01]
case/Main Keyboard.dxf
385.5 x 383.1

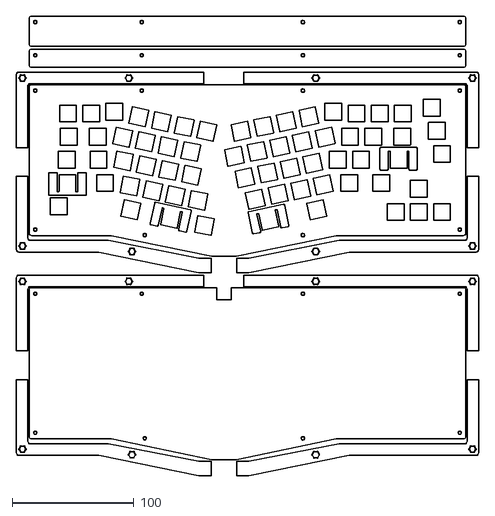
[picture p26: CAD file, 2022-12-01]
case/arisu_lopro_case_P2_ponoko.dxf
380.2 x 378.3

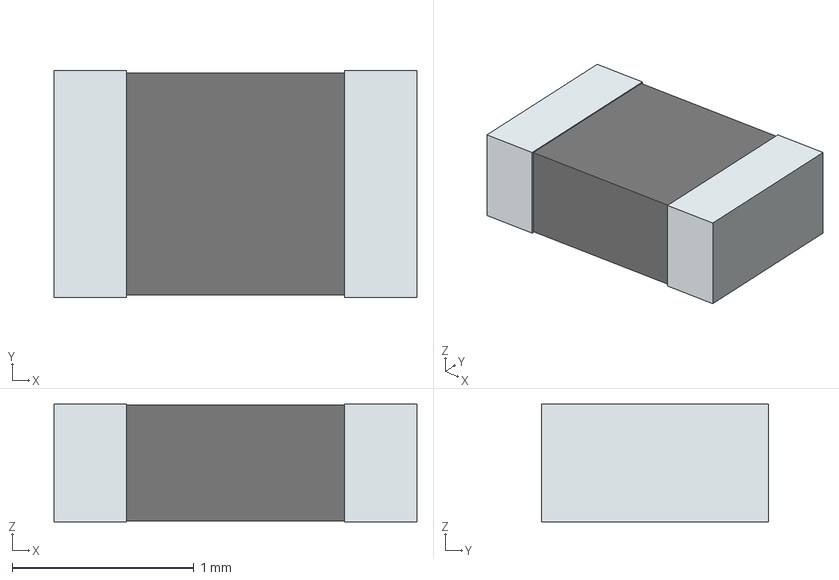
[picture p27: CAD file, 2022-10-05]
parts/100K/3D/KTR10EZPF1003.stp
2.00 x 1.25 x 0.65 mm
term1
term2

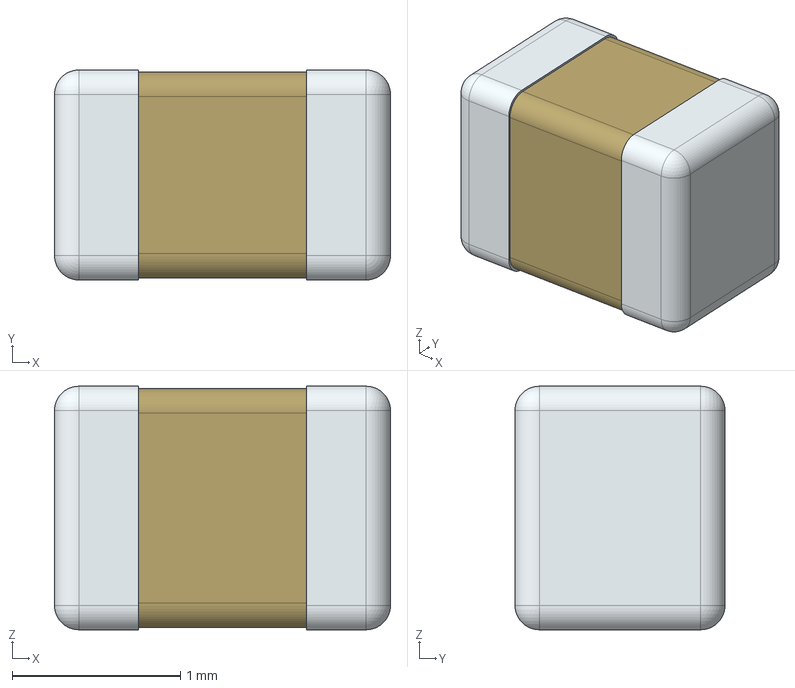
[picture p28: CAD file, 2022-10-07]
parts/10uF/3D/TMK212BBJ106MG-T.stp
2.00 x 1.25 x 1.45 mm

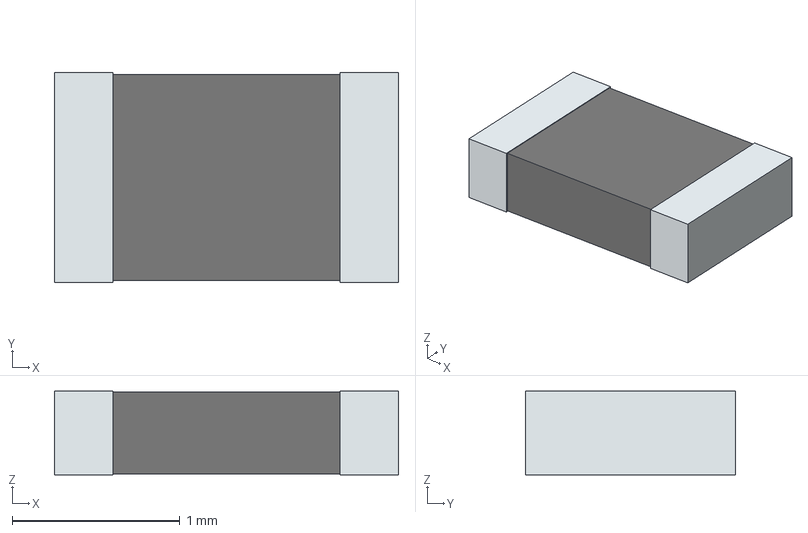
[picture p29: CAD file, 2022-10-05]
parts/5.1k/3D/CRCW08055K10JNTA.stp
2.05 x 1.25 x 0.5 mm
term1
term2

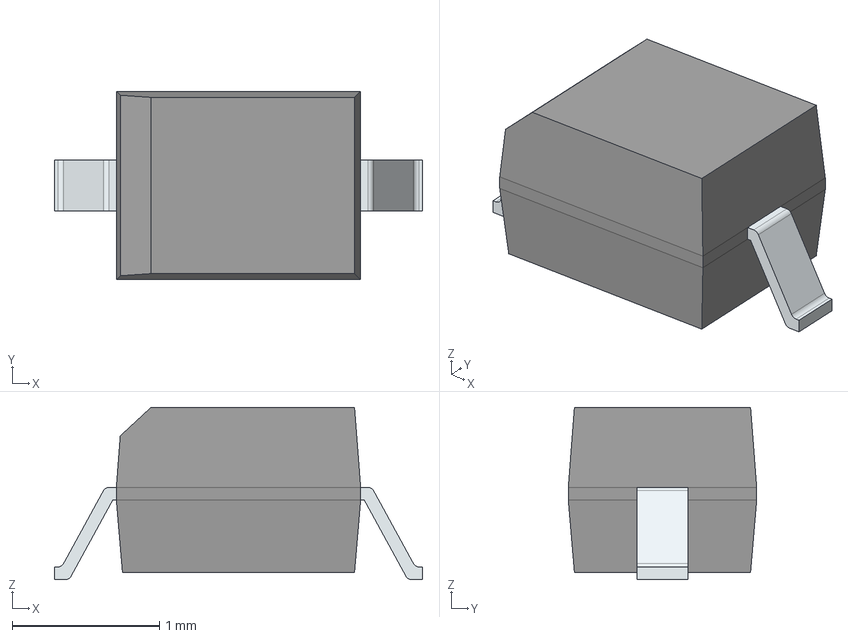
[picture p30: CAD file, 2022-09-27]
parts/BAT60JFILM/3D/BAT60JFILM.stp
2.50 x 1.28 x 1.17 mm
FilletPinL
FilletPinR

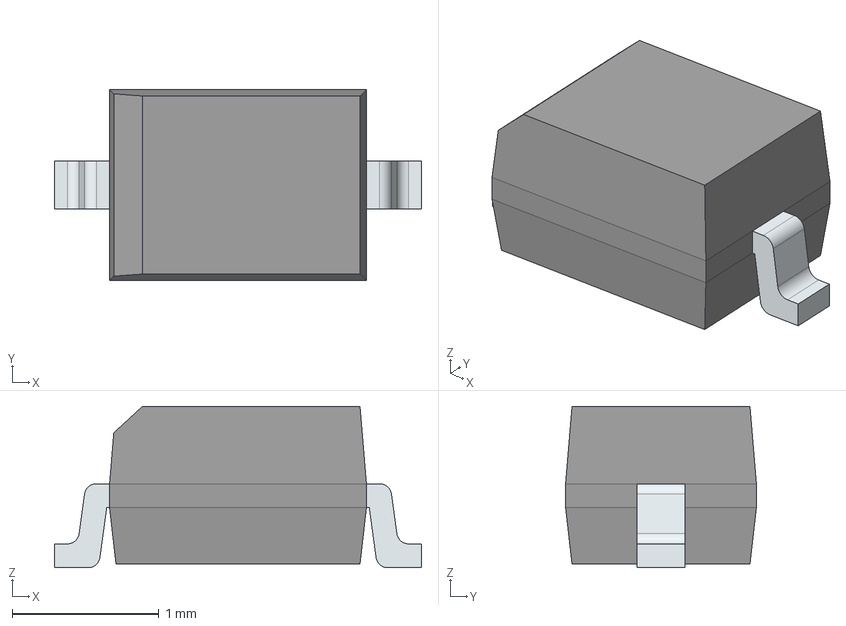
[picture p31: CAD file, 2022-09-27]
parts/BAT_60B_E6327/3D/BAT_60B_E6327.stp
2.50 x 1.30 x 1.10 mm
FilletPinL
FilletPinR

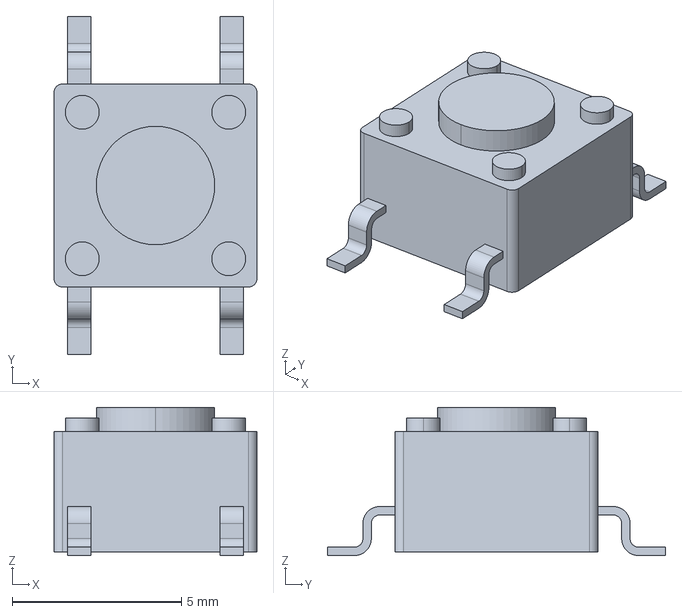
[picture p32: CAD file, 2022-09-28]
parts/Button/3D/FSM2JSMAATR.stp
6.00 x 10.0 x 4.38 mm

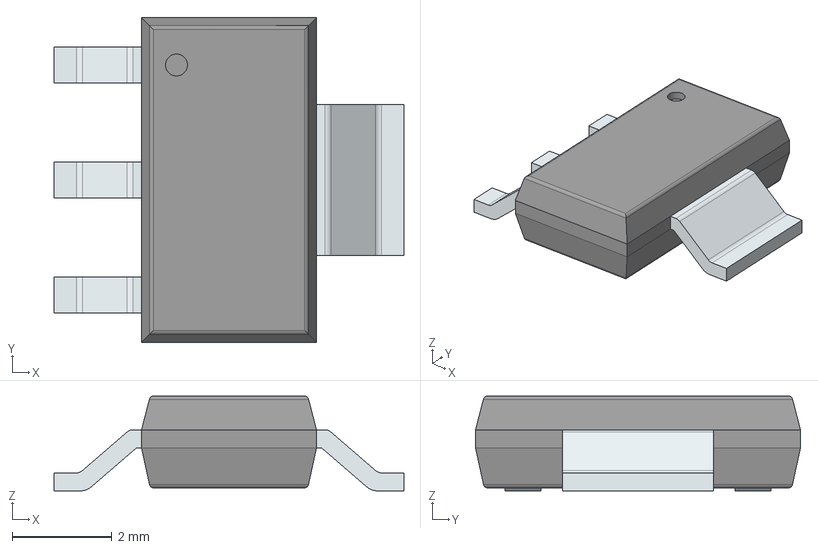
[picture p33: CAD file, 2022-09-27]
parts/LD1117ASTR/3D/LD1117ASTR.stp
7.00 x 6.50 x 1.90 mm
PinsArrayL
FilletPinR

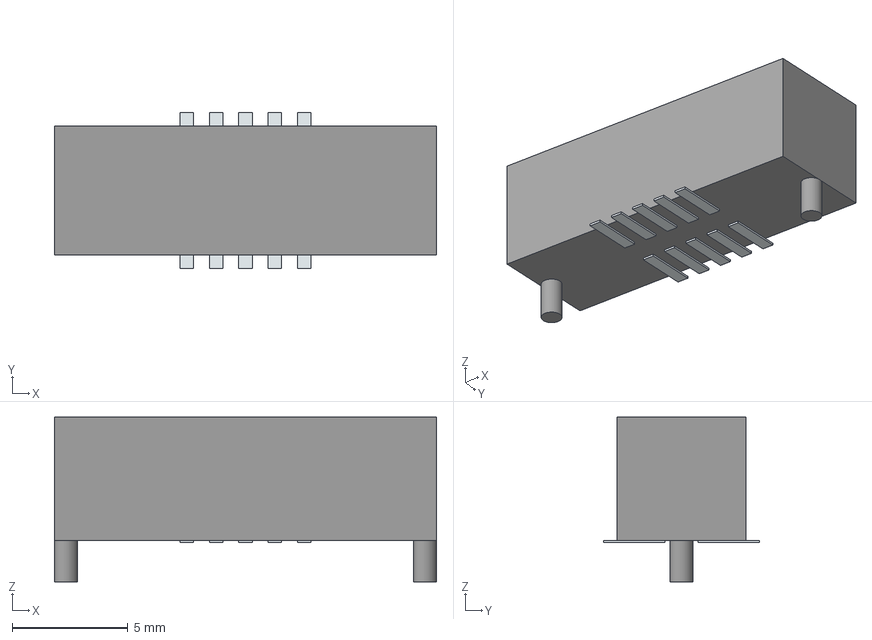
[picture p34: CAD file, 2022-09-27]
parts/Program Header/3D/ESHF-105-01-F-D-SM-LC.stp
16.5 x 6.73 x 7.13 mm
Pins
Lugs x 2

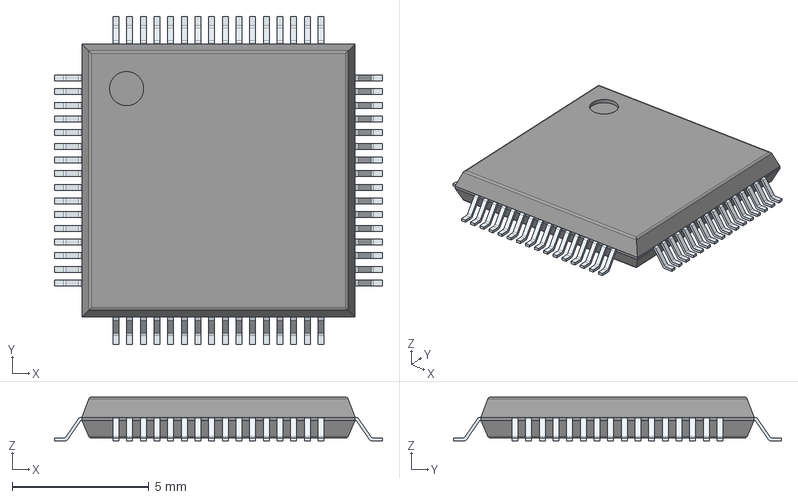
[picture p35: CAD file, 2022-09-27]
parts/STM32F091RCT6/3D/STM32F091RCT6.stp
12.0 x 12.0 x 1.60 mm
PinsArrayLR
PinsArrayTB

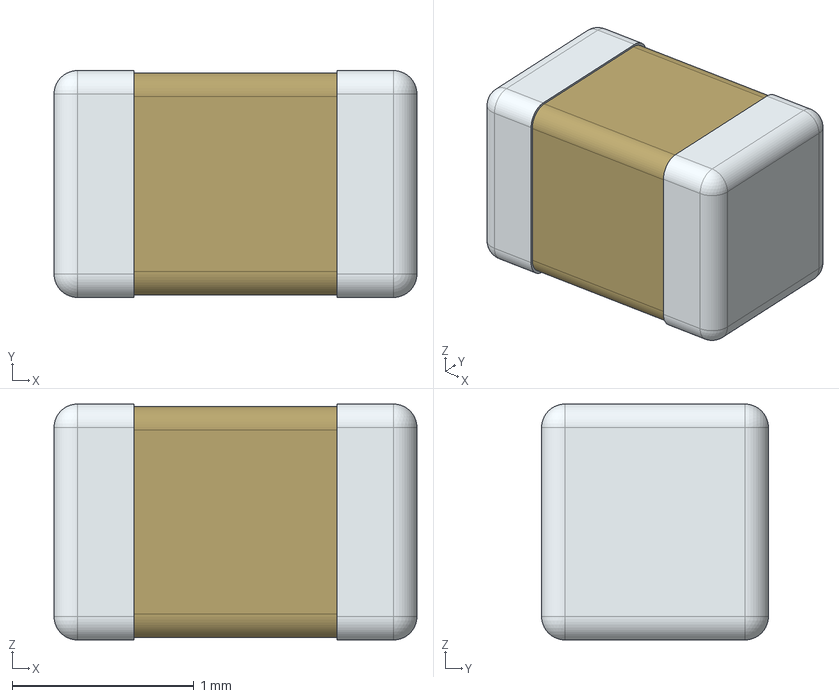
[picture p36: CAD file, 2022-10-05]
parts/.1uF/3D/0805J0630104MXT.stp
2.00 x 1.25 x 1.30 mm

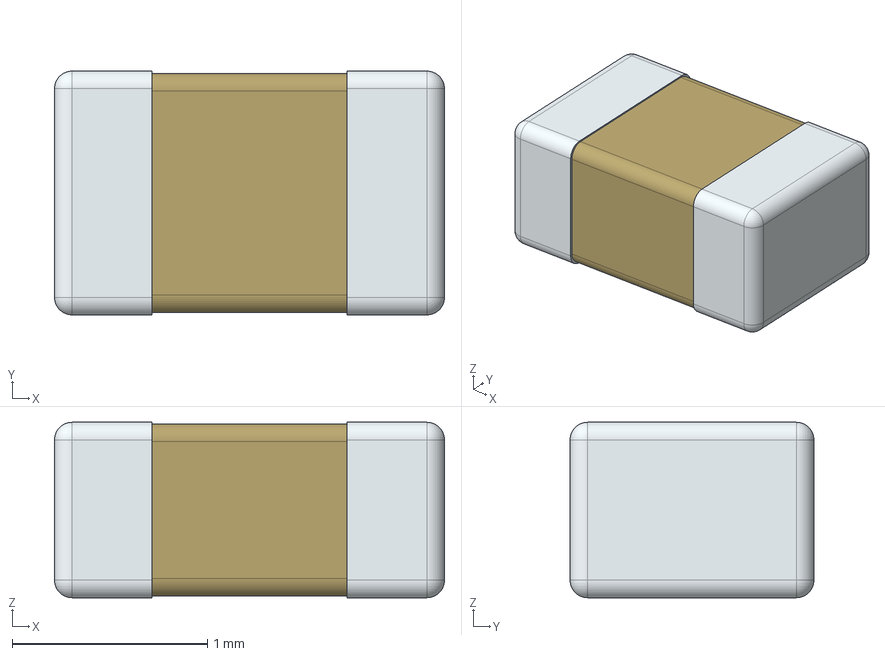
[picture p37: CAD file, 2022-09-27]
parts/Ferrite Bead/3D/7427920415.stp
2.00 x 1.25 x 0.9 mm

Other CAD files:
parts/10R/3D/KTR10EZPJ100.stp
parts/1k/3D/CRT0805-FZ-1001ELF.stp
parts/22uF/3D/C0805C226K7PAC7800.stp
case/Submodule-Bottom.dxf
case/Submodule-Top.dxf
case/Main Keyboard.dwg
case/Submodule-Bottom.dwg
case/Submodule-Top.dwg
case/arisu_lopro_case_P2_ponoko.dwg
parts/.1uF/Allegro/capc2012x130n.psm
parts/.1uF/DEHDL/0805j0630104mxt/chips/chips.prt
parts/100K/Allegro/resc2012x65n.psm
parts/100K/DEHDL/ktr10ezpf1003/chips/chips.prt
parts/10R/Allegro/resc2012x65n.psm
parts/10R/DEHDL/ktr10ezpj100/chips/chips.prt
parts/10uF/Allegro/capc2012x145n.psm
parts/10uF/DEHDL/tmk212bbj106mg_t/chips/chips.prt
parts/1k/Allegro/resc2012x65n.psm
parts/1k/DEHDL/crt0805_fz_1001elf/chips/chips.prt
parts/22uF/Allegro/capc2012x140n.psm
parts/22uF/DEHDL/c0805c226k7pac7800/chips/chips.prt
parts/5.1k/Allegro/resc2012x50n.psm
parts/5.1k/DEHDL/crcw08055k10jnta/chips/chips.prt
parts/BAT60JFILM/Allegro/sod2513x117n.psm
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

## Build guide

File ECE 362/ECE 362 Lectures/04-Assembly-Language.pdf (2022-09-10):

# Assembly Language Programming

# ECE 362 https://engineering.purdue.edu/ece362/

© 2021, Rick. All Rights Reserved. Redistribution Prohibited.

# Reading you should have done

- Textbook, Chapter 7,”Structured Programming”, pages 133 – 160.
– Today’s topic.

# - Textbook, Chapter 8, “Subroutines”, pages 161

– 202.
– Also today.

# Upcoming reading

## - Textbook, Chapter 10, “Mixing C and Assembly”, pages 215 –

236.
– We’ll talk about this soon.

## - Textbook, Chapter 14, “General Purpose I/O (GPIO)”, pages

341 – 372.
– We’ll talk about this in the next lecture module.
- Textbook, Chapter 11, “Interrupts”, pages 237 – 268.
– We’ll talk about this later on.

Limit instructions to those recognized by Cortex-M0.
We don’t have a floating-point hardware.
Use unified syntax.
Use 16- and 32-bit Thumb instruction set (not 32-bit ARM instructions). Put following items in read-write memory.
Put following items in read-only memory.
Replace name with replacement. (like #define)
Reserve and initialize 1 byte of storage for each element in a list of 8-bit integers. Reserve and initialize 2 bytes of storage for each element in a list of 16-bit integers. Reserve and initialize 4 bytes of storage for each element in a list of 32-bit integers. Reserve S bytes of storage. Do not initialize.
Reserve space for the characters plus a null byte terminator.
One of either of the following:
Align the following item on a B-byte boundary.
Align the following item on a 2B-byte boundary.
Make the given symbol visible to outside modules.

# Assembler Directives

- .cpu cortex-m0
- .fpu softvfp
- .syntax unified
- .thumb
- .data
- .text
- .equ name, replacement
- .byte n [, n, n, n, ...]
- .hword n [, n, n, n, ...]
- .word n [, n, n, n, ...]
- .space S
- .string “...”
- .align B
– .balign B
– .b2align B
- .global symbol

Don’t forget comma.

Think in C. Code in Assembly.

- We’re going to start writing major programs in assembly language.

## - The easiest way to do that (that I know of) is to think about what

you want in C, and then translate it into assembly language.
- C becomes the modeling language.

## - There are three things we need to understand:

### – How to represent variables and arrays – How to represent control flow (if, while, do, for) – How to represent subroutines

# C-to-Assembly Translation: Variable Update Via Register

int x;
x = x + 1;
ldr r0, =x | // load addr of x
ldr r1, [r0] | // load value of x
adds r1, #1 | // add one to value
str r1, [r0] | // store result to x

…
.balign 4 | // literal pool
lit_pool: | // added automatically
.word x

.data
x: .space 4

# C-to-Assembly Translation: Variable Update Via Register

int x;
x = x + 1;

ldr r0, lit_pool// load addr of x
ldr r1, [r0] | // load value of x
adds r1, #1 | // add one to value
str r1, [r0] | // store result to x

…
.balign 4 | // literal pool
lit_pool: | // if we added, manually
.word x

.data
x: .space 4

# C-to-Assembly Translation: Statements

x = alpha + beta * gamma; | ldr r0, =alpha | // load addr of alpha
| ldr r1, [r0] | // load value of alpha
| ldr r0, =beta | // load addr of beta
| ldr r2, [r0] | // load value of beta
| ldr r0, =gamma | // load addr of gamma
| ldr r3, [r0] | // load value of gamma
| muls r2, r3 | // r2 = r2 * r3
| adds r1,r1,r2 | // r1 = r1 + r2
| ldr r0, =x | // load addr of x
| str r1, [r0] | // store result to x
| …
.balign 4 // literal pool added automatically alpha_addr: .word alpha
beta_addr: .word beta
gamma_addr: .word gamma
x_addr: .word x

.data
.balign 4
alpha: .space 4
beta: .space 4
gamma: .space 4
x: | .space 4

# C-to-Assembly Translation: Statements

x = alpha + beta * gamma; | ldr r0, alpha_addr // load addr of alpha
ldr r1, [r0] | // load value of alpha
ldr r0, beta_addr | // load addr of beta
ldr r2, [r0] | // load value of beta
ldr r0, gamma_addr // load addr of gamma
ldr r3, [r0] | // load value of gamma
muls r2, r3 | // r2 = r2 * r3
adds r1,r1,r2 | // r1 = r1 + r2
ldr r0, x_addr | // load addr of x
str r1, [r0] | // store result to x
…
.balign 4
alpha_addr: .word alpha
beta_addr: .word beta
gamma_addr: .word gamma
x_addr: .word x

Same as before
but manual creation
of the literal pool...

.data
.balign 4
alpha: .space 4
beta: .space 4
gamma: .space 4
x: | .space 4

# C-to-Assembly Translation: Statements

x = alpha + beta * gamma; | ldr r0, vars | // load addr of alpha
| ldr r1, [r0] | // load value of alpha
| ldr r2, [r0, #4] | // load value of beta
| ldr r3, [r0, #8] | // load value of gamma
| muls r2, r3 | // r2 = r2 * r3
| adds r1,r1,r2 | // r1 = r1 + r2
| str r1, [r0, #12] | // store result to x
| …
| .balign 4
| vars: .word alpha

.data
.balign 4
alpha: .space 4
beta: .space 4
gamma: .space 4
x: | .space 4

Same as before
but manual creation
of a single-entry literal pool when placement of all
variables is known.

# C-to-Assembly Translation: Statements

x = alpha + beta * gamma; | ldr r0, =alpha | // load addr of alpha
| ldr r1, [r0] | // load value of alpha
| ldr r2, [r0, #4] | // load value of beta
| ldr r3, [r0, #8] | // load value of gamma
| muls r2, r3 | // r2 = r2 * r3
| adds r1,r1,r2 | // r1 = r1 + r2
| str r1, [r0, #12] | // store result to x
.data
.balign 4
alpha: .space 4
beta: .space 4
gamma: .space 4
x: | .space 4

Same as before
but automatic creation
of the literal pool
when placement of all
variables is known.

# C-to-Assembly Translation: "if-then-else"

if (expr) {
then_statements; …
} else {
else_statements; …
}

if1:
expr
…
branch_if_not else1
then1:
then_statements
…
b endif1
else1:
else_statements
…
endif1:

# C-to-Assembly Translation: "if-then-else" example

if | (x > 100) | {
x = x - 1;
} else {
x = x + 1;
}

if1:
ldr r0, =x
ldr r1, [r0]
cmp r1, #100
ble else1
then1:
ldr r0, =x
ldr r1, [r0]
subs r1, #1
str r1, [r0]
b endif1
else1:
ldr r0, =x
ldr r1, [r0]
adds r1, #1
str r1, [r0]
endif1:

Branch is
always based
on the opposite
of the condition
tested for.

# C-to-Assembly Translation: "do-while"

do {
do_body_stmts; ...
} while (expr);

do1:
do_body_stmts
while1:
expr
branch_if_yes do1
enddo1:

# C-to-Assembly Translation: "do-while" example

do {
x = x >> 1;
} while (x > 2);

do1:
ldr r0, =x
ldr r1, [r0]
asrs r1, r1, #1
str r1, [r0]
while1:
ldr r0, =x
ldr r1, [r0]
cmp r1, #2
bgt do1
enddo1:

# C-to-Assembly Translation: "while"

while (expr) {
while_body_stmts; ...
}

while1:
expr
branch_if_not endwhile1
do1:
while_body_stmts; …
b while1
endwhile1:

# C-to-Assembly Translation: "while" example

while (x > y) {
y = y + 1;
}

while1:
ldr r0, =x
ldr r1, [r0]
ldr r0, =y
ldr r2, [r0]
cmp r1, r2
ble endwhile1
do1:
ldr r0, =y
ldr r1, [r0]
adds r1, #1
str r1, [r0]
b while1
endwhile1:

# C-to-Assembly Translation: "for"

for (init; check; next_stmt) { for_body_stmts; ...
}

for1:
init
forcond1:
check
branch_if_not fordone1
forbody1:
for_body_stmts; …
fornext1:
next_stmt
b forcond1
fordone1:

init;
while (check) {
for_body_stmts; …
next_stmt;
}

# C-to-Assembly Translation: "for" example

for (q=0; n>=d; q++) {
n = n - d;
}
r = n;

for1:
ldr r0, =q
movs r1, #0
str r1, [r0]
forcond1:
ldr r0, =n
ldr r1, [r0]
ldr r0, =d
ldr r2, [r0]
cmp r1, r2
blt fordone1
forbody1:
ldr r0, =n
ldr r1, [r0]
ldr r0, =d
ldr r2, [r0]
subs r1, r1, r2
ldr r0, =n
str r1, [r0]
fornext1:
ldr r0, =q;
ldr r1, [r0]
adds r1, #1
str r1, [r0]
b forcond1

fordone1:
ldr r0, =n
ldr r1, [r0]
ldr r0, =r
str r1, [r0]

# Simple Division

- The ARM Cortex-M0 has no divide instruction. – You should feel lucky that it has a multiply.

## - Simple way to divide one number by another:

– Initialize the quotient to be zero.
– While numerator >= denominator,
- Subtract the divisor (denom.) from the numerator
- Increment the quotient
– The dividend (numerator) is now the remainder.

for (q=0; n>=d; q++) {
n = n - d;
}
r = n;

# Division Example:

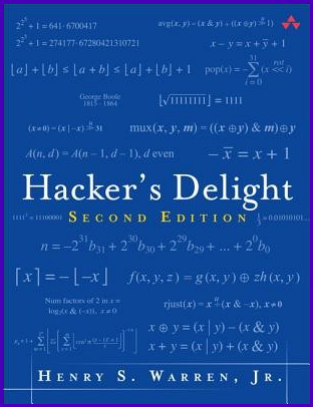
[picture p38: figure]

- 90 / 12: quotient = 0
- 78 / 12: quotient = 1
- 66 / 12: quotient = 2
- 54 / 12: quotient = 3
- 42 / 12: quotient = 4
- 30 / 12: quotient = 5
- 18 / 12: quotient = 6
- 6 / 12: quotient = 7
- Done. Quotient = 7, Remainder = 6 "Can’t we do this any faster?"
Yes.

# Consider a simple program:

int x;
int main(void) {
x = x + 1;
empty_subroutine();
x = x – 2;
}

void empty_subroutine(void) { }

- Let’s use subroutines this time.

# – How do we even do this?

# The Stack: Subroutines

- The Cortex-M0 has a stack pointer (SP), but no JSR instruction. – Recall that JSR on the simple computer:
- Decremented (subtracted one from) SP
- Wrote PC of next instruction to [SP]
- Jumped to immediate argument.
– Cannot have all that complexity in a RISC CPU. – To invoke a subroutine with a Cortex-M0 CPU, we:
- save pointer to next instruction in Link Register (LR)
- branch to the destination address
- Instruction is BL (Branch with Link)
- It is the callee’s responsibility to save the LR

BL: (branch with link)

“Put the current PC
into the LR register
and branch to the
given label.”

# Example of BL

ldr | r0,=x
ldr | r1,[r0]
adds | r1,r1,#1
str | r1,[r0]
bl | empty_subroutine
ldr | r0,=x
ldr | r1,[r0]
subs | r1,r1,#2
str | r1,[r0]
bkpt
…

empty_subroutine:
bx lr

.data
x: .word 1

"Wait, you didn’t even use the stack there."

True. This is the smallest example possible.

BX: Branch and Exchange

“Put the contents of the
specified register into the PC.”

Example 0 on
lecture notes page

# Saving LR on the Stack

## - Cortex-M0 has PUSH and POP instructions:

## – PUSH:

- Decrement SP (multiple times).
- Write multiple registers into memory pointed to by SP.
– One of those registers can be LR.

## – POP:

- Read multiple registers from memory pointed to by SP.
– One of those registers can be PC.
- | Increment SP (multiple times). | See ARMv6-M Architecture
| | Reference Manual
| | Section A6.7.49

See ARMv6-M Architecture
Reference Manual
Section A6.7.50

# A Real Subroutine

.syntax unified
.cpu cortex-m0
.thumb

.global main
main:
movs | r0, #25 | // initialize r0 with 25
bl | incr0 | // "call" incr0. LR is next instruction.
bkpt | | // What is value of r0 when we get here?

incr0:
push | {lr} | // Save the LR “on the stack”
adds | r0, #1 | // Add 1 to r0
pop | {pc} | // Pop one word “from the stack” to PC.

# More Complex Functions

# - Consider this C program:

# – main calls first

## - first calls second - first calls second again

# – main calls first again

## - first calls second - first calls second again

# - first and second must know where to return to!

int x = 0;

int main() {
first();
first();
}

void first() {
second();
second();
}

void second() {
x += 1;
}

By the way, what’s
the final value of x?

# Don’t always need to save LR

int x = 0;

int main() {
first();
first();
}

void first() {
second();
second();
}

void second() {
x += 1;
}

first() must save LR
before calling second()

.data
x: .word 0
.text
.global main
main:
bl | first
bl | first
bkpt
first:
push {lr}
bl | second
bl | second
pop {pc}
second:
ldr r0, =x
ldr r1, [r0]
adds r1, #1
str r1, [r0]
bx lr

first() returns with pop {pc}

second() is a “leaf function”. It calls no other functions, so LR will not be overwritten. No need to push it.

Example 1 on
lecture notes page

# We can save more registers with PUSH/POP than just LR/PC

.syntax unified
.cpu cortex-m0
.thumb

.global main
main:
movs | r0, #25 | // initialize r0 with 25
bl | incr0 | // "call" incr0. LR is next instruction.
nop
bkpt | | // What is value of r0 when we get here?

incr0:
push | {r1-r4,r6,lr} | // Save lots of registers to the stack
adds | r0, #1 | // Add 1 to r0
pop | {r1-r4,r6,pc} | // Pop several words from stack
r1-r4 means R1 through R4 (R1,R2,R3,R4)

Example 2 (or something similar) on lecture notes page

0x20008000

0x20000000

# Be Careful With Stack Memory

## - Your development board has 32K (32768) bytes

of SRAM (static random-access memory).
– 0x20000000 – 0x20007fff
- SP is initialized to 0x20008000.

### – (It is decremented by 4 before writing a word to memory.)

## - Things like variables in the data segment start at

0x20000000.
- It’s really all the same memory.
- If you keep pushing things onto the stack,
you will eventually overwrite variables.

(pushed)
(pushed)

(variable)

(variable)

(variable)

(variable)

(pushed)
(pushed)
(pushed)
(pushed)
(pushed)
(pushed)
(pushed)
(pushed)
(pushed)
(pushed)

# Consider a recursive subroutine:

sum: | push {lr} | // save link register
if1: | cmp r0,#0 | // x > 0
ble endif1 | // no? goto endif1
ldr r1,=total // get addr of total
ldr r2,[r1] | // load from total
adds r2,r0 | // total = total + x
str r2,[r1] | // store total
subs r0,#1 | // x - 1
bl | sum | // sum(x - 1)
endif1: nop
pop {pc} | // return

.global main
main:
movs r0, #3
bl sum
wfi
.data
total .word 0

int total = 0;

int sum(int x) {
if (x > 0) {
total += x;
sum(x-1);
}
}

int main() {
sum(3);
} | Example 3 on lecture notes page

# Application Binary Interface

- Every platform defines an ABI for functions and subroutines.
- Ours looks like this:
– The caller passes the first four parameters in R0-R3.
- Any more parameters go on the stack.
– The callee is allowed to modify R0-R3 and R12.
- If any other registers are changed, they must first be saved to the stack.
– The return value from a function is in R0.
- These are the rules if you want your assembly language functions to get along with C functions.
– We can do anything we want if we’re writing our own code in assembly language, but a C compiler maintains certain expectations. When we link in C code, we have to play by the rules.

# Why have an ABI?

# - Clearly defines who needs to save registers and

when.

# - As long as everyone adheres to the ABI, you know that fn() will

not mess with R4 – R11.

# - calc() saves and restores R4 so that any caller can

trust it not to modify R4.

## calc: push {r4,lr} movs r4,r0 movs r0, #3 bl fn adds r0,r4 pop {r4,pc}

## int calc(int x) {

return x + fn(3);
}

# Consequences of the ABI

- You almost never want to save and restore R0. – Don’t push or pop that.

# - You almost never need to save and restore

R1 – R3 or R12.

# - Generally, if you need to use R4 – R11, save them at the beginning of your subroutine and restore them at

subroutine exit.

# Check the “Bonus Lectures”

# - There are many nuances of subroutines that

are difficult for students to understand.

# - The course textbook has good coverage of

these topics.

# - Otherwise, go through the bonus lectures on

subroutines and recursive flow control.

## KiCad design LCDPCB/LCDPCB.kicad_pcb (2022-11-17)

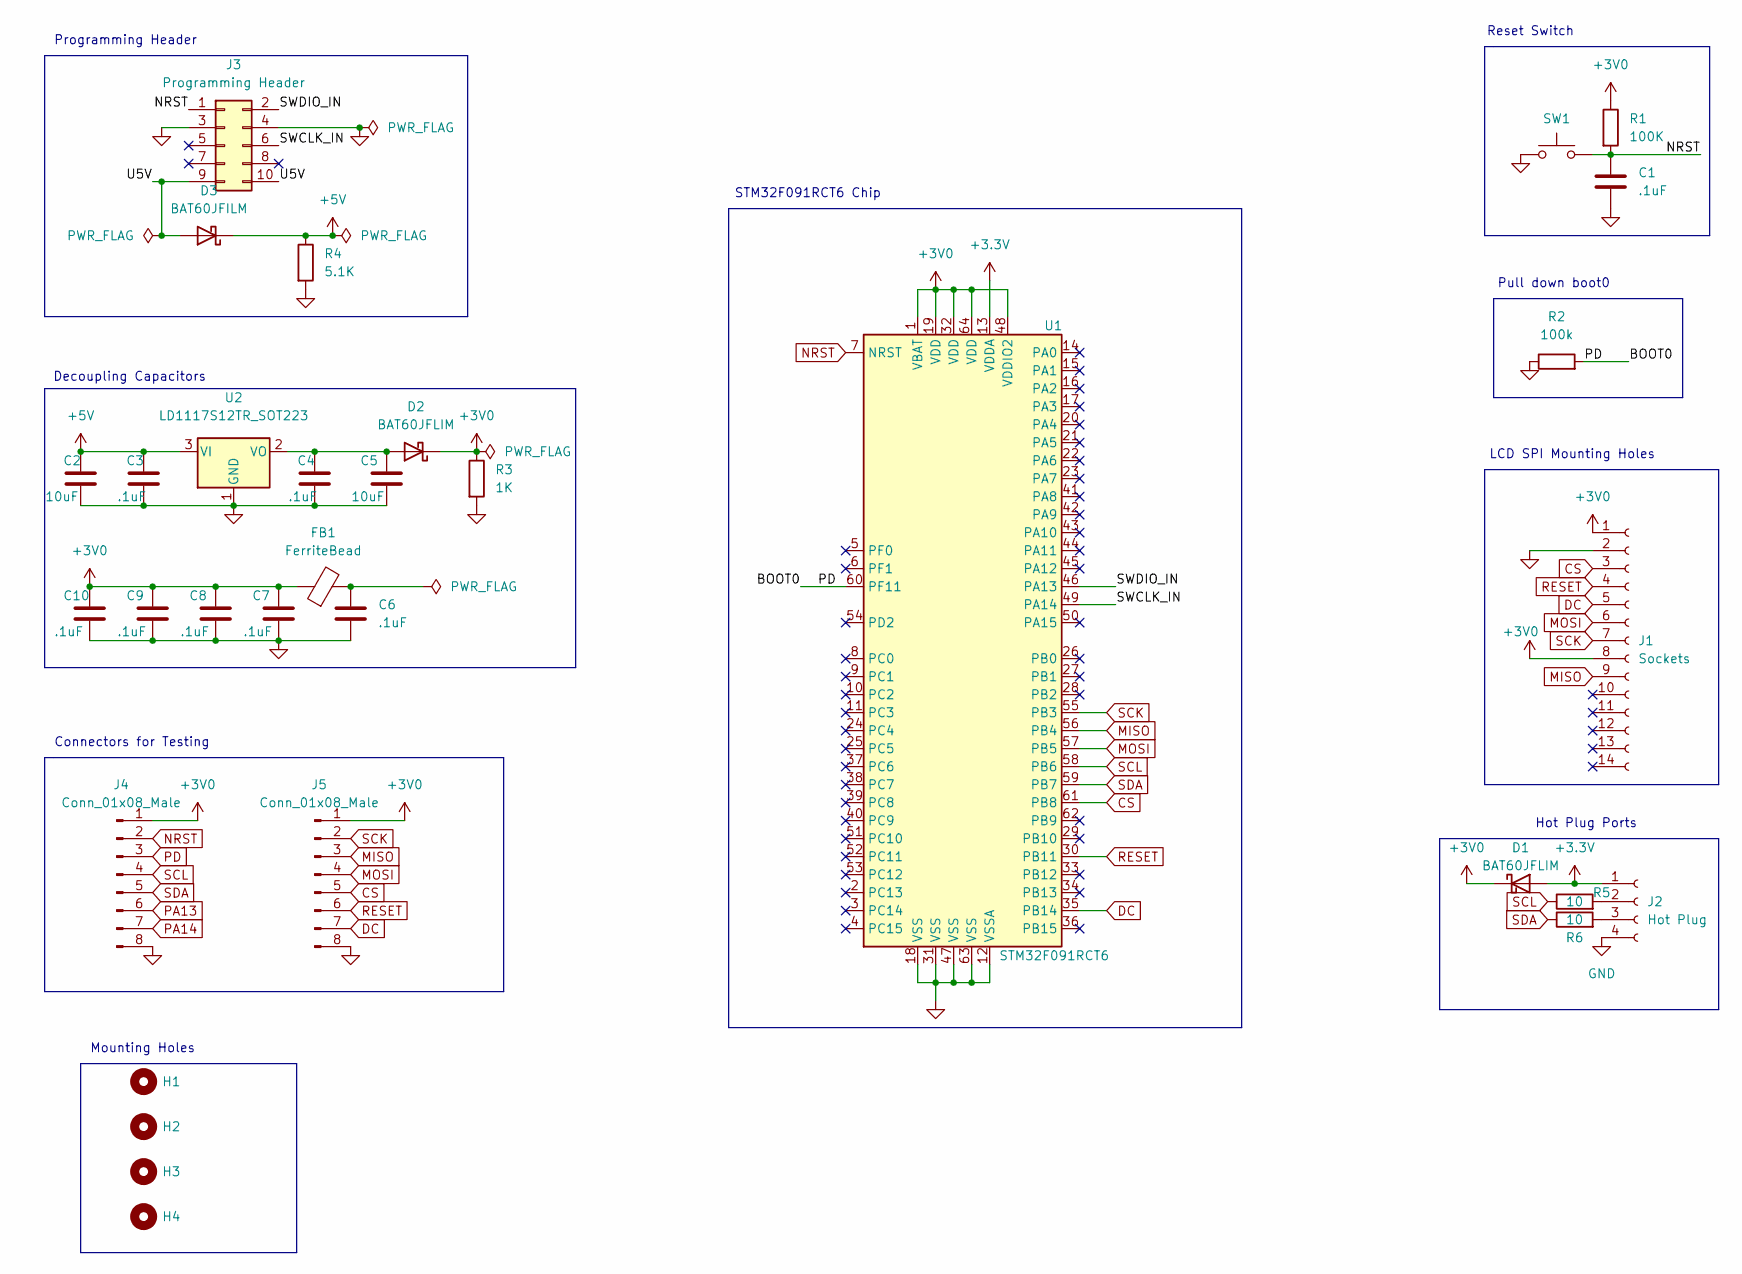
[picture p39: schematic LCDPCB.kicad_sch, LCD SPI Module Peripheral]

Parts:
C1, C3, C4, C6, C7, C8, C9, C10: .1uF
C2: 10uF; new10uf
C5: 10uF
D1, D2: BAT60JFLIM; BAT60JFILM
D3: BAT60JFILM
FB1: FerriteBead; Ferrite
H1, H2, H3, H4: MountingHole; MountingHole_2.2mm_M2_ISO7380
J1: Sockets; PinSocket_1x14_P2.54mm_Vertical
J2: Hot Plug; PinSocket_1x04_P2.54mm_Vertical
J3: Programming Header; PinSocket_2x05_P2.54mm_Vertical
J4, J5: Conn_01x08_Male; PinHeader_1x08_P2.54mm_Vertical
R1: 100K; 100k
R2: 100k
R3: 1K; 1k
R4: 5.1K; 5.1k
R5, R6: 10; 10R
SW1: SW_Push; Button
U1: STM32F091RCT6; STM32F091
U2: LD1117S12TR_SOT223; SOT-223-3_TabPin2

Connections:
+3.3V: D1.2 (A), J2.1, U1.13 (VDDA)
+3V0: C7.1, C8.1, C9.1, C10.1, D1.1 (K), D2.1 (K), FB1.1, J1.1, J1.8, J4.1, J5.1, R1.1, R3.1, U1.1 (VBAT), U1.19 (VDD), U1.32 (VDD), U1.48 (VDDIO2), U1.64 (VDD)
+5V: C2.1, C3.1, D3.1 (K), R4.1, U2.3 (VI)
/SWCLK_IN: J3.6, U1.49 (PA14)
/SWDIO_IN: J3.2, U1.46 (PA13)
/U5V: D3.2 (A), J3.9, J3.10
CS: J1.3, J5.5, U1.61 (PB8)
DC: J1.5, J5.7, U1.35 (PB14)
GND: C1.2, C2.2, C3.2, C4.2, C5.2, C6.2, C7.2, C8.2, C9.2, C10.2, J1.2, J2.4, J3.3, J3.4, J4.8, J5.8, R2.1, R3.2, R4.2, SW1.1, U1.12 (VSSA), U1.18 (VSS), U1.31 (VSS), U1.47 (VSS), U1.63 (VSS), U2.1 (GND)
MISO: J1.9, J5.3, U1.56 (PB4)
MOSI: J1.6, J5.4, U1.57 (PB5)
NRST: C1.1, J3.1, J4.2, R1.2, SW1.2, U1.7 (NRST)
unnamed: C4.1, C5.1, D2.2 (A), U2.2 (VO)
unnamed: C6.1, FB1.2
unnamed: J2.2, R5.2
unnamed: J2.3, R6.2
PA13: J4.6
PA14: J4.7
PD: J4.3, R2.2, U1.60 (PF11)
RESET: J1.4, J5.6, U1.30 (PB11)
SCK: J1.7, J5.2, U1.55 (PB3)
SCL: J4.4, R5.1, U1.58 (PB6)
SDA: J4.5, R6.1, U1.59 (PB7)

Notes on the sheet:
Mounting Holes
Reset Switch
STM32F091RCT6 Chip
Programming Header
Connectors for Testing
Pull down boot0
Decoupling Capacitors
Hot Plug Ports
LCD SPI Mounting Holes

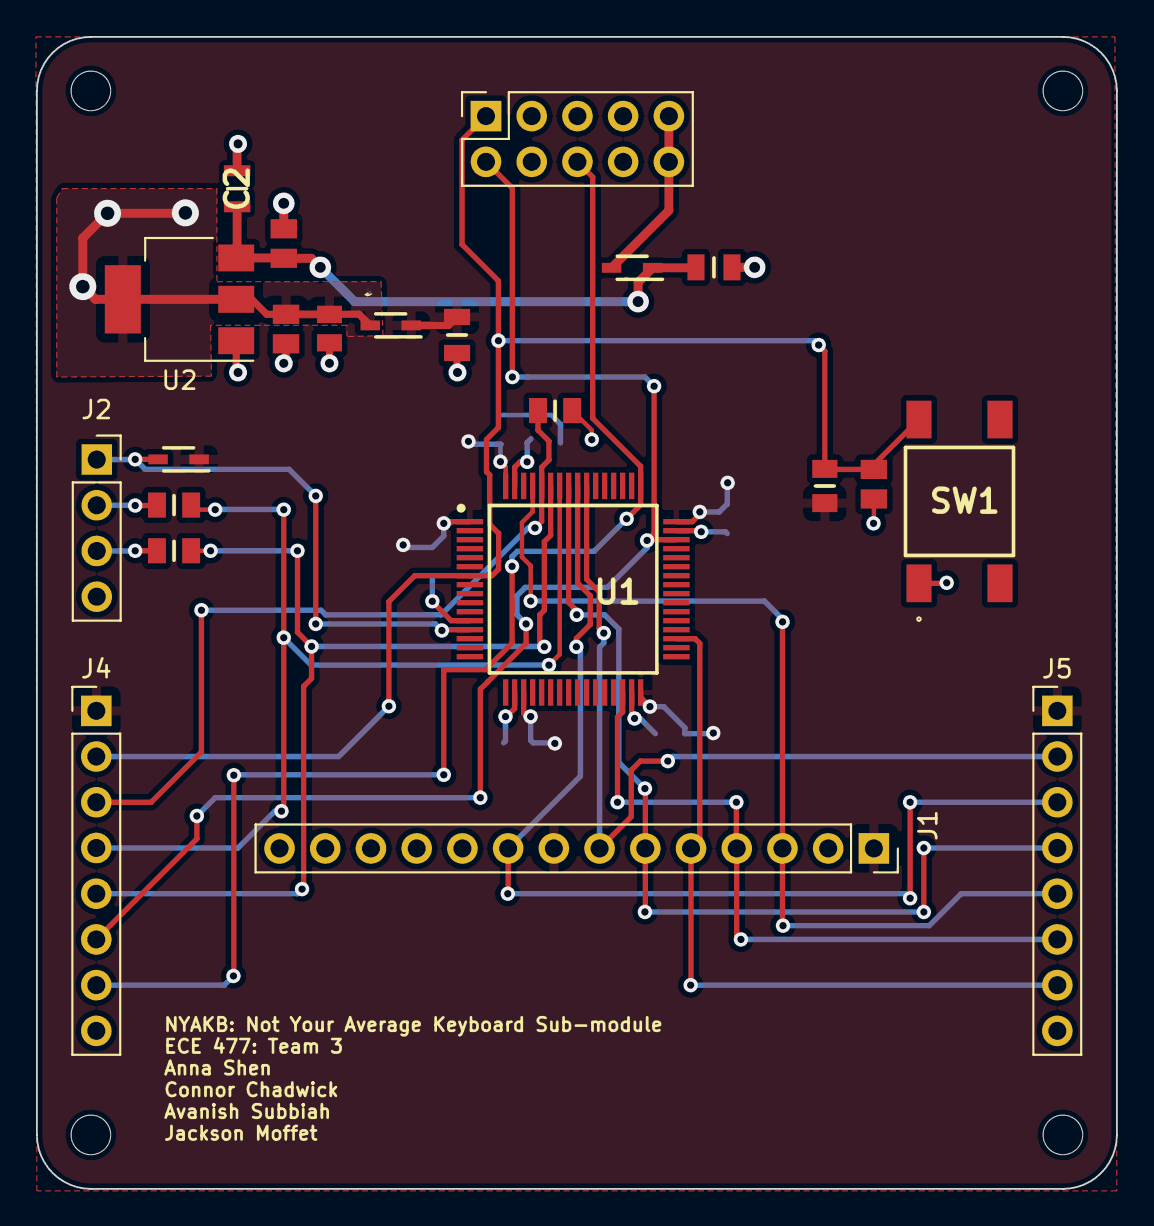
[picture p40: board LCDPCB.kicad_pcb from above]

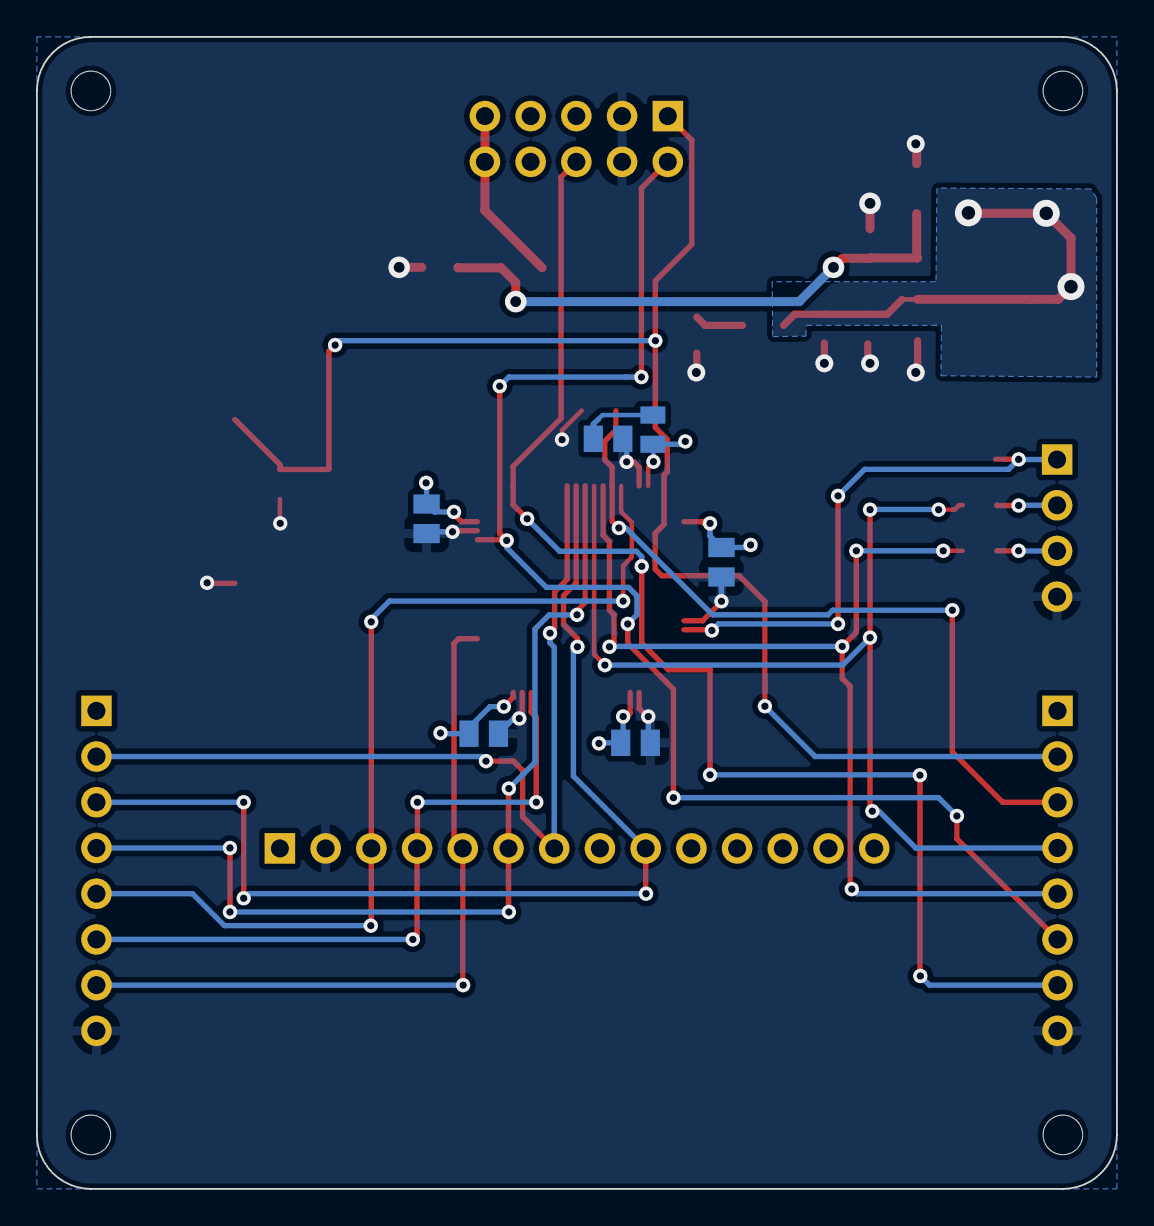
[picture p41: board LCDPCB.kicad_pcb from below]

Board: 2 copper layers, 60.0 x 64.0 mm, 32 parts (6 on the bottom side), 21 nets.

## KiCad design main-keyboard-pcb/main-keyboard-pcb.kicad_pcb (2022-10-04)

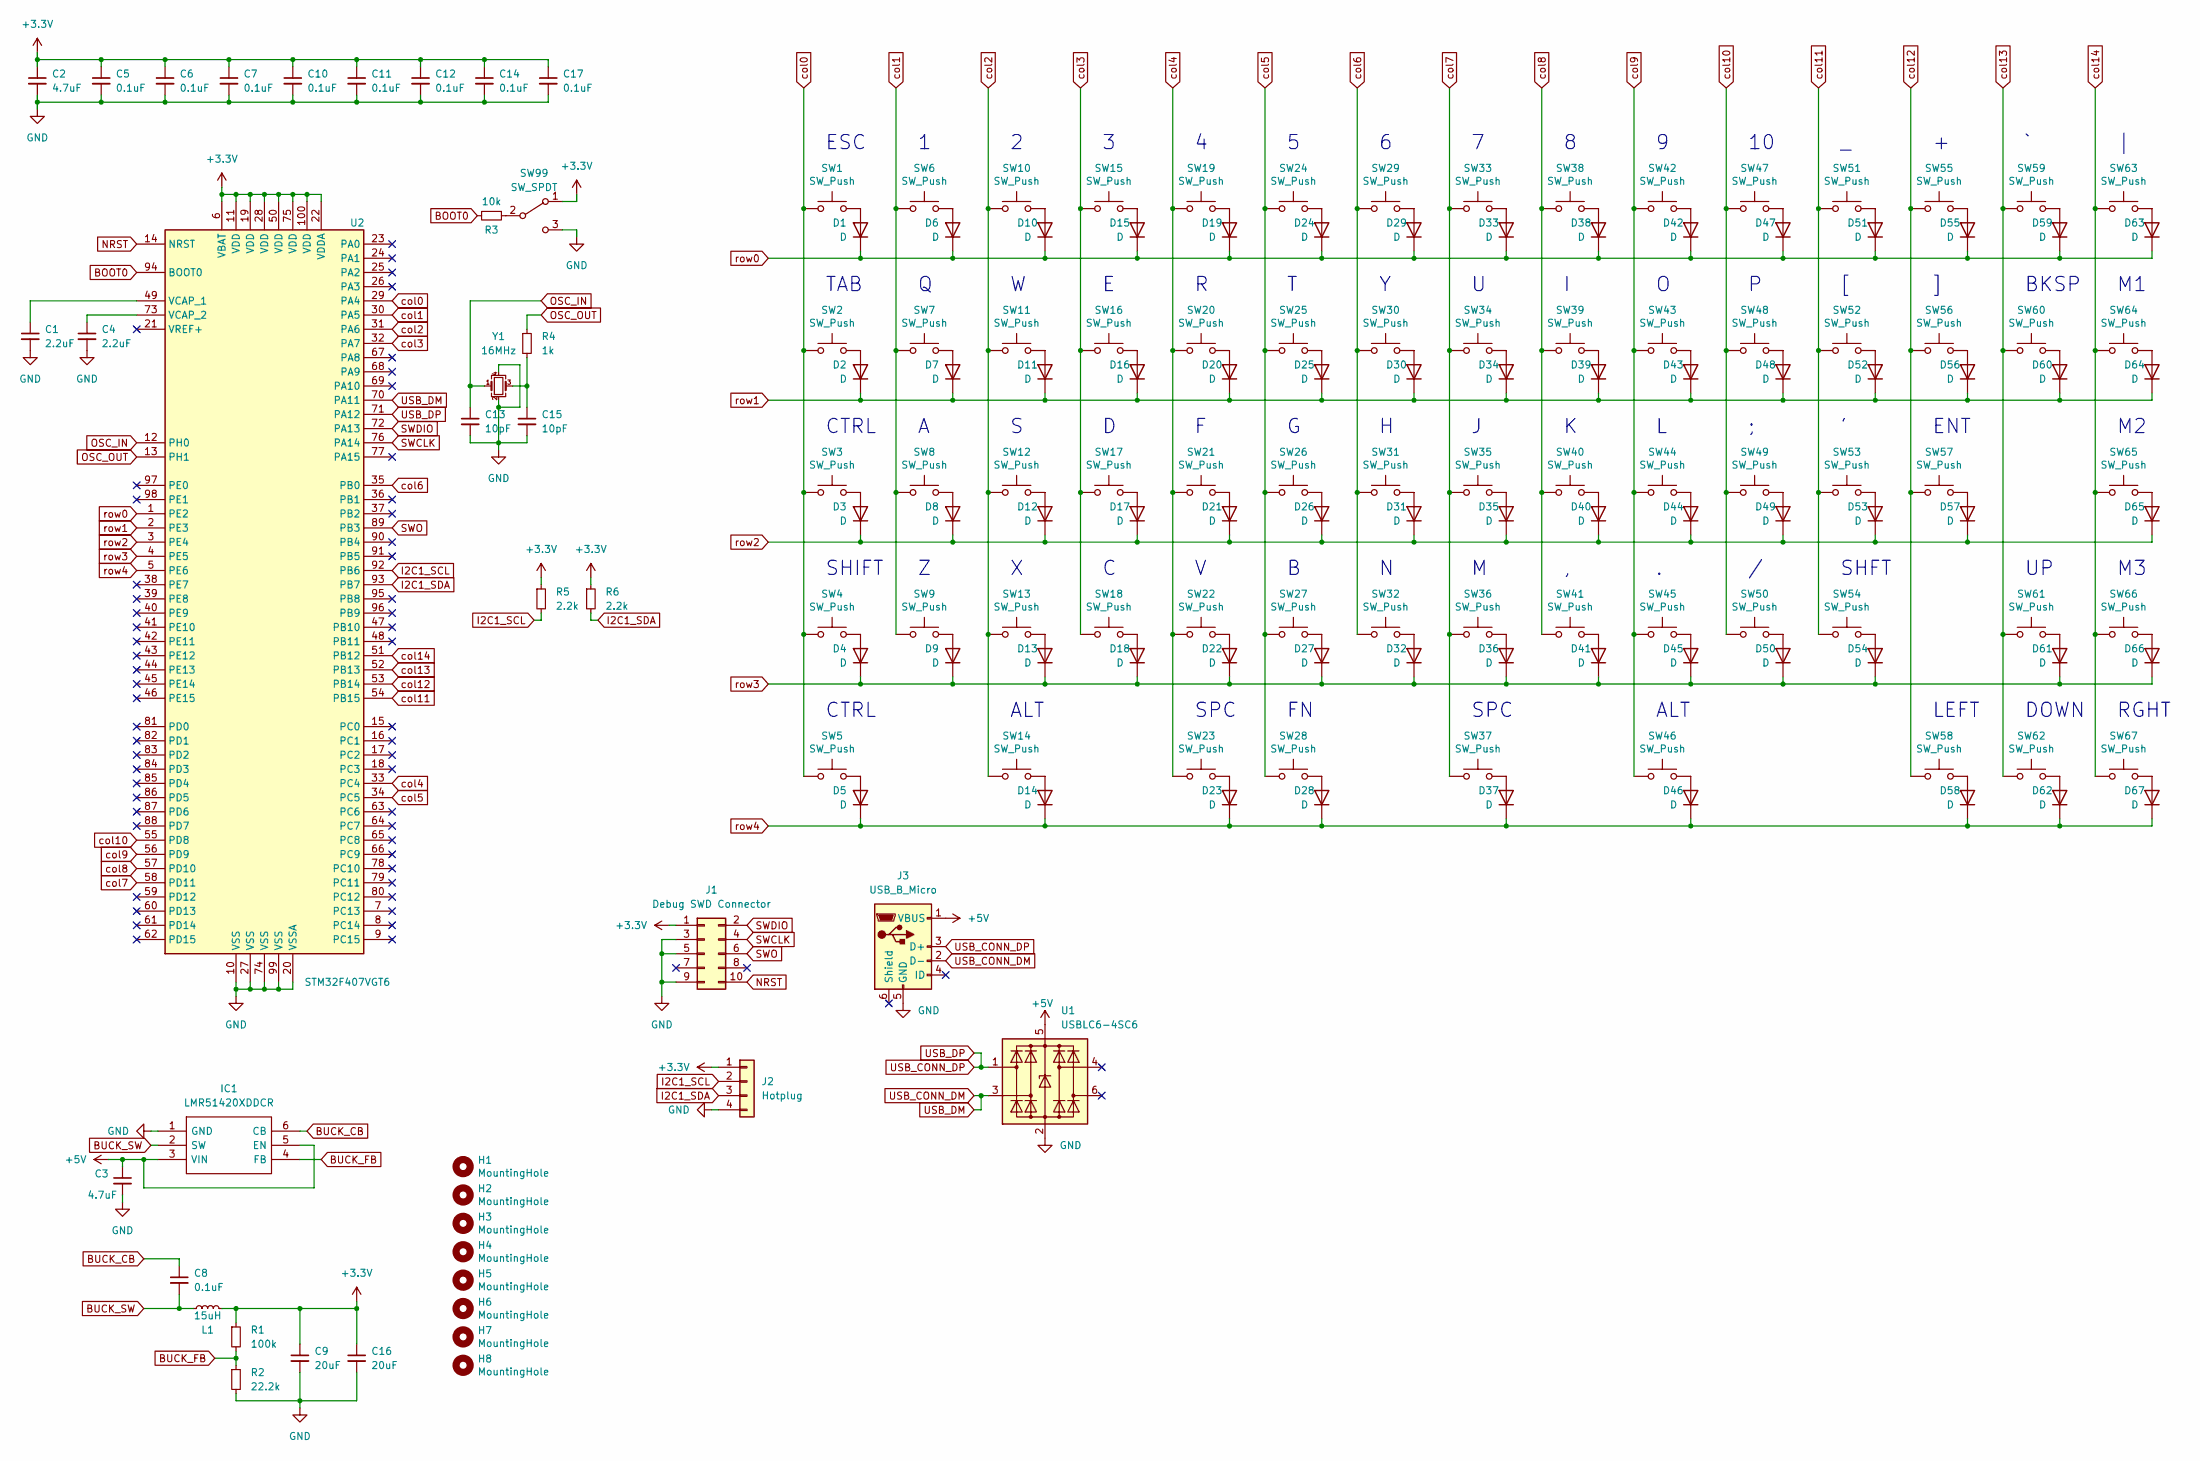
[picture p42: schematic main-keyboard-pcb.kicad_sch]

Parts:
C1, C4: 2.2uF; GRM155R61E225KE11D
C2, C3: 4.7uF; GRM188R61C475KAAJD
C5, C6, C7, C8, C10, C11, C12, C14, C17: 0.1uF; GRM022R61A104ME01L
C9, C16: 20uF; GRMJN7R61C206ME05D
C13, C15: 10pF; GRM0225C1C100FA03L
D1, D2, D3, D4, D5, D6, D7, D8, D9, D10, D11, D12, D13, D14, D15, D16, D17, D18, D19, D20, D21, D22, D23, D24, D25, D26, D27, D28, D29, D30, D31, D32, D33, D34, D35, D36, D37, D38, D39, D40, D41, D42, D43, D44, D45, D46, D47, D48, D49, D50, D51, D52, D53, D54, D55, D56, D57, D58, D59, D60, D61, D62, D63, D64, D65, D66, D67: D; 1N4148W-13-F
H1, H2, H3, H4, H5, H6, H7, H8: MountingHole; MountingHole_2.2mm_M2_Pad
IC1: LMR51420XDDCR; Manufacturer_Part_Number LMR51420XDDCR
J1: Debug SWD Connector; PinHeader_2x05_P1.27mm_Vertical_SMD
J2: Hotplug; PinHeader_1x04_P2.54mm_Vertical
J3: USB_B_Micro; USB307530A
L1: 15uH; SRP1265WA150M
R1: 100k; CHV1206AJW-104ELF
R2: 22.2k; ERJP08F2212V
R3: 10k; ERJ-UP3F1002V
R4: 1k; ERJ-UP3D1001V
R5, R6: 2.2k; ERJ-UP3F2201V
SW1, SW6, SW7, SW8, SW9, SW10, SW11, SW12, SW13, SW15, SW16, SW17, SW18, SW19, SW20, SW21, SW22, SW24, SW25, SW26, SW27, SW28, SW29, SW30, SW31, SW32, SW33, SW34, SW35, SW36, SW38, SW39, SW40, SW41, SW42, SW43, SW44, SW45, SW47, SW48, SW49, SW50, SW51, SW52, SW53, SW55, SW56, SW58, SW59, SW61, SW62, SW63, SW64, SW65, SW66, SW67: SW_Push; SW_Cherry_MX_1.00u_PCB
SW2, SW5, SW14, SW46, SW60: SW_Push; SW_Cherry_MX_1.50u_PCB
SW3, SW54: SW_Push; SW_Cherry_MX_1.75u_PCB
SW4: SW_Push; SW_Cherry_MX_2.25u_PCB
SW23: SW_Push; SW_Cherry_MX_2.00u_PCB_ReversedStabilizers
SW37: SW_Push; SW_Cherry_MX_2.75u_PCB_ReversedStabilizers
SW57: SW_Push; SW_Cherry_MX_2.25u_PCB_ReversedStabilizers
SW99: SW_SPDT; SW_SPDT_PCM12
U1: USBLC6-4SC6; SOT-23-6
U2: STM32F407VGT6; LQFP-100_14x14mm_P0.5mm
Y1: 16MHz; ECS-160-10-30B-CKM-TR

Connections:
+3V3: C2.1, C5.1, C6.1, C7.1, C9.1, C10.1, C11.1, C12.1, C14.1, C16.1, C17.1, J1.1, J2.1, L1.2, R1.1, R5.1, R6.1, SW99.1 (A), U2.6 (VBAT), U2.11 (VDD), U2.19 (VDD), U2.22 (VDDA), U2.28 (VDD), U2.50 (VDD), U2.75 (VDD), U2.100 (VDD)
+5V: C3.1, IC1.3 (VIN), IC1.5 (EN), J3.1 (VBUS), U1.5 (VBUS)
BOOT0: R3.2, U2.94 (BOOT0)
BUCK_CB: C8.1, IC1.6 (CB)
BUCK_FB: IC1.4 (FB), R1.2, R2.1
BUCK_SW: C8.2, IC1.2 (SW), L1.1
GND: C1.2, C2.2, C3.2, C4.2, C5.2, C6.2, C7.2, C9.2, C10.2, C11.2, C12.2, C13.2, C14.2, C15.2, C16.2, C17.2, IC1.1 (GND), J1.3, J1.5, J1.9, J2.4, J3.5 (GND), R2.2, SW99.3 (C), U1.2 (GND), U2.10 (VSS), U2.20 (VSSA), U2.27 (VSS), U2.74 (VSS), U2.99 (VSS), Y1.2, Y1.4
I2C1_SCL: J2.2, R5.2, U2.92 (PB6)
I2C1_SDA: J2.3, R6.2, U2.93 (PB7)
NRST: J1.10, U2.14 (NRST)
unnamed: C1.1, U2.49 (VCAP_1)
unnamed: C4.1, U2.73 (VCAP_2)
unnamed: C15.1, R4.2, Y1.3
unnamed: D1.2 (A), SW1.2
unnamed: D2.2 (A), SW2.2
unnamed: D3.2 (A), SW3.2
unnamed: D4.2 (A), SW4.2
unnamed: D5.2 (A), SW5.2
unnamed: D6.2 (A), SW6.2
unnamed: D7.2 (A), SW7.2
unnamed: D8.2 (A), SW8.2
unnamed: D9.2 (A), SW9.2
unnamed: D10.2 (A), SW10.2
unnamed: D11.2 (A), SW11.2
unnamed: D12.2 (A), SW12.2
unnamed: D13.2 (A), SW13.2
unnamed: D14.2 (A), SW14.2
unnamed: D15.2 (A), SW15.2
unnamed: D16.2 (A), SW16.2
unnamed: D17.2 (A), SW17.2
unnamed: D18.2 (A), SW18.2
unnamed: D19.2 (A), SW19.2
unnamed: D20.2 (A), SW20.2
unnamed: D21.2 (A), SW21.2
unnamed: D22.2 (A), SW22.2
unnamed: D23.2 (A), SW23.2
unnamed: D24.2 (A), SW24.2
unnamed: D25.2 (A), SW25.2
unnamed: D26.2 (A), SW26.2
unnamed: D27.2 (A), SW27.2
unnamed: D28.2 (A), SW28.2
unnamed: D29.2 (A), SW29.2
unnamed: D30.2 (A), SW30.2
unnamed: D31.2 (A), SW31.2
unnamed: D32.2 (A), SW32.2
unnamed: D33.2 (A), SW33.2
unnamed: D34.2 (A), SW34.2
unnamed: D35.2 (A), SW35.2
unnamed: D36.2 (A), SW36.2
unnamed: D37.2 (A), SW37.2
unnamed: D38.2 (A), SW38.2
unnamed: D39.2 (A), SW39.2
unnamed: D40.2 (A), SW40.2
unnamed: D41.2 (A), SW41.2
unnamed: D42.2 (A), SW42.2
unnamed: D43.2 (A), SW43.2
unnamed: D44.2 (A), SW44.2
unnamed: D45.2 (A), SW45.2
unnamed: D46.2 (A), SW46.2
unnamed: D47.2 (A), SW47.2
unnamed: D48.2 (A), SW48.2
unnamed: D49.2 (A), SW49.2
unnamed: D50.2 (A), SW50.2
unnamed: D51.2 (A), SW51.2
unnamed: D52.2 (A), SW52.2
unnamed: D53.2 (A), SW53.2
unnamed: D54.2 (A), SW54.2
unnamed: D55.2 (A), SW55.2
unnamed: D56.2 (A), SW56.2
unnamed: D57.2 (A), SW57.2
unnamed: D58.2 (A), SW58.2
unnamed: D59.2 (A), SW59.2
unnamed: D60.2 (A), SW60.2
unnamed: D61.2 (A), SW61.2
unnamed: D62.2 (A), SW62.2
unnamed: D63.2 (A), SW63.2
unnamed: D64.2 (A), SW64.2
unnamed: D65.2 (A), SW65.2
unnamed: D66.2 (A), SW66.2
unnamed: D67.2 (A), SW67.2
unnamed: R3.1, SW99.2 (B)
OSC_IN: C13.1, U2.12 (PH0), Y1.1
OSC_OUT: R4.1, U2.13 (PH1)
SWCLK: J1.4, U2.76 (PA14)
SWDIO: J1.2, U2.72 (PA13)
SWO: J1.6, U2.89 (PB3)
USB_CONN_DM: J3.2 (D-), U1.3 (I/O2), U2.70 (PA11)
USB_CONN_DP: J3.3 (D+), U1.1 (I/O1), U2.71 (PA12)
col0: SW1.1, SW2.1, SW3.1, SW4.1, SW5.1, U2.29 (PA4)
col1: SW6.1, SW7.1, SW8.1, SW9.1, U2.30 (PA5)
col2: SW10.1, SW11.1, SW12.1, SW13.1, SW14.1, U2.31 (PA6)
col3: SW15.1, SW16.1, SW17.1, SW18.1, U2.32 (PA7)
col4: SW19.1, SW20.1, SW21.1, SW22.1, SW23.1, U2.33 (PC4)
col5: SW24.1, SW25.1, SW26.1, SW27.1, SW28.1, U2.34 (PC5)
col6: SW29.1, SW30.1, SW31.1, SW32.1, U2.35 (PB0)
col7: SW33.1, SW34.1, SW35.1, SW36.1, SW37.1, U2.58 (PD11)
col8: SW38.1, SW39.1, SW40.1, SW41.1, U2.57 (PD10)
col9: SW42.1, SW43.1, SW44.1, SW45.1, SW46.1, U2.56 (PD9)
col10: SW47.1, SW48.1, SW49.1, SW50.1, U2.55 (PD8)
col11: SW51.1, SW52.1, SW53.1, SW54.1, U2.54 (PB15)
col12: SW55.1, SW56.1, SW57.1, SW58.1, U2.53 (PB14)
col13: SW59.1, SW60.1, SW61.1, SW62.1, U2.52 (PB13)
col14: SW63.1, SW64.1, SW65.1, SW66.1, SW67.1, U2.51 (PB12)
row0: D1.1 (K), D6.1 (K), D10.1 (K), D15.1 (K), D19.1 (K), D24.1 (K), D29.1 (K), D33.1 (K), D38.1 (K), D42.1 (K), D47.1 (K), D51.1 (K), D55.1 (K), D59.1 (K), D63.1 (K), U2.1 (PE2)
row1: D2.1 (K), D7.1 (K), D11.1 (K), D16.1 (K), D20.1 (K), D25.1 (K), D30.1 (K), D34.1 (K), D39.1 (K), D43.1 (K), D48.1 (K), D52.1 (K), D56.1 (K), D60.1 (K), D64.1 (K), U2.2 (PE3)
row2: D3.1 (K), D8.1 (K), D12.1 (K), D17.1 (K), D21.1 (K), D26.1 (K), D31.1 (K), D35.1 (K), D40.1 (K), D44.1 (K), D49.1 (K), D53.1 (K), D57.1 (K), D65.1 (K), U2.3 (PE4)
row3: D4.1 (K), D9.1 (K), D13.1 (K), D18.1 (K), D22.1 (K), D27.1 (K), D32.1 (K), D36.1 (K), D41.1 (K), D45.1 (K), D50.1 (K), D54.1 (K), D61.1 (K), D66.1 (K), U2.4 (PE5)
row4: D5.1 (K), D14.1 (K), D23.1 (K), D28.1 (K), D37.1 (K), D46.1 (K), D58.1 (K), D62.1 (K), D67.1 (K), U2.5 (PE6)

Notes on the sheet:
TAB
SPC
ESC
RGHT
ALT
ENT
LEFT
BKSP
SHIFT
CTRL
SHFT
DOWN

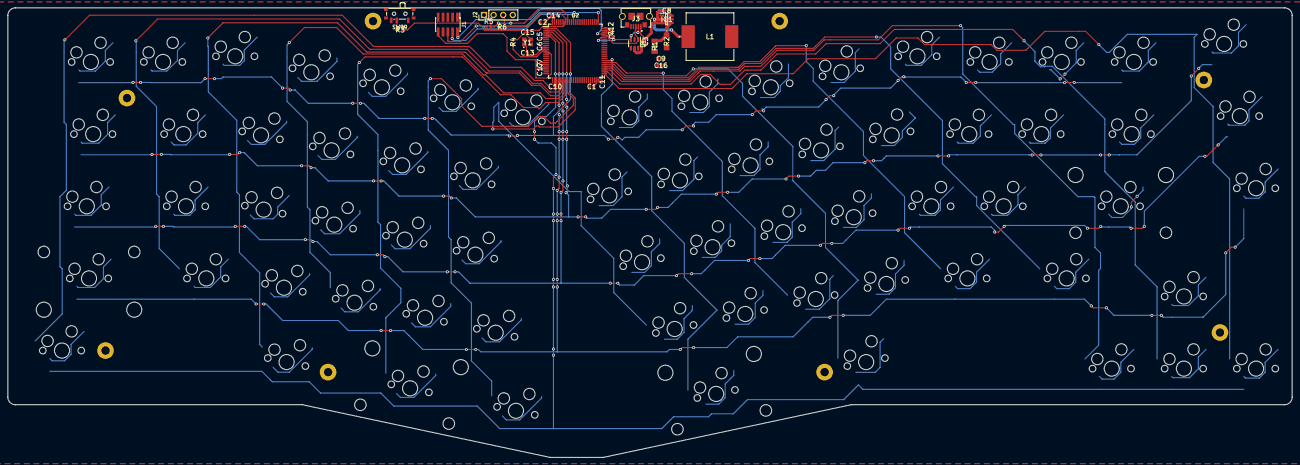
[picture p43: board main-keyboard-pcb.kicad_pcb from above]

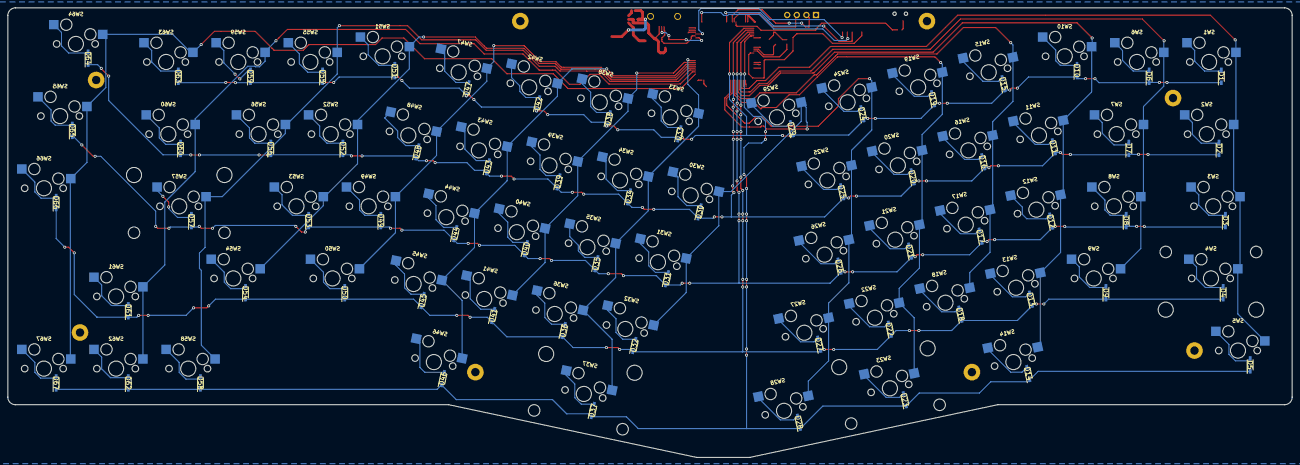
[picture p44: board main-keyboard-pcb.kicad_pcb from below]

Board: 4 copper layers, 339.1 x 118.7 mm, 174 parts (67 on the bottom side), 108 nets.

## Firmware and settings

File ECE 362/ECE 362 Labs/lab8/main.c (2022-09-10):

#include "stm32f0xx.h"
#include "string.h"

// Be sure to change this to your login...
const char login[] = "subbiah";

void nano_wait(unsigned int n) {
    asm(    "        mov r0,%0\n"
            "repeat: sub r0,#83\n"
            "        bgt repeat\n" : : "r"(n) : "r0", "cc");
}


//===========================================================================
// 2.1 FROM LAB 6
// ..........................................................................
// Configuring GPIO
//===========================================================================
void enable_ports(void) {
    // Enable RCC to GPIOB and GPIOC
    RCC->AHBENR |= RCC_AHBENR_GPIOBEN;
    RCC->AHBENR |= RCC_AHBENR_GPIOCEN;

    // GPIOB PB0-10 Outputs
    GPIOB->MODER &= ~0x3FFFFF; // Clear PB0-10
    GPIOB->MODER |= 0x155555;

    // GPIOC PC4-7 Outputs
    GPIOC->MODER &= ~0xFF00;
    GPIOC->MODER |= 0x5500;

    // GPIOC PC0-3 Inputs
    GPIOC->MODER &= ~0xFF;
    // GPIOC PC0-3 Pull Down
    GPIOC->PUPDR &= ~0xFF;
    GPIOC->PUPDR |= 0xAA;
}

//===========================================================================
// Debouncing a Keypad
//===========================================================================
const char keymap[] = "DCBA#9630852*741";
uint8_t hist[16];
uint8_t col;
char queue[2];
int qin;
int qout;

void drive_column(int c) {
    GPIOC->BSRR = 0xf00000 | (1 << (c + 4));
}

int read_rows() {
    return GPIOC->IDR & 0xf;
}

void push_queue(int n) {
    n = (n & 0xff) | 0x80;
    queue[qin] = n;
    qin ^= 1;
}

uint8_t pop_queue() {
    uint8_t tmp = queue[qout] & 0x7f;
    queue[qout] = 0;
    qout ^= 1;
    return tmp;
}

void update_history(int c, int rows) {
    for(int i = 0; i < 4; i++) {
        hist[4*c+i] = (hist[4*c+i]<<1) + ((rows>>i)&1);
        if (hist[4*c+i] == 1)
          push_queue(4*c+i);
    }
}

void init_tim6() {
    RCC->APB1ENR |= RCC_APB1ENR_TIM6EN;
    TIM6->PSC = 48 - 1;
    TIM6->ARR = 1000 - 1;
    TIM6->DIER |= TIM_DIER_UIE;
    TIM6->CR1 |= TIM_CR1_CEN;
    NVIC->ISER[0] |= 1 << TIM6_DAC_IRQn;
}

void TIM6_DAC_IRQHandler(void) {
    TIM6->SR &= ~TIM_SR_UIF;
    int rows = read_rows();
    update_history(col, rows);
    col = (col + 1) & 3;
    drive_column(col);
}

char get_keypress() {
    for(;;) {
        asm volatile ("wfi" : :);   // wait for an interrupt
        if (queue[qout] == 0)
            continue;
        return keymap[pop_queue()];
    }
}




//===========================================================================
// This Lab 7
// ..........................................................................
// 2.2 Bit Bang SPI LED Array
//===========================================================================
int msg_index = 0;
uint16_t msg[8] = { 0x0000,0x0100,0x0200,0x0300,0x0400,0x0500,0x0600,0x0700 };
extern const char font[];

void append_display(char val) {
    for (int i = 1; i < sizeof(msg); i++) {
        msg[i-1] &= ~0xff;
        msg[i-1] |= (i-1)<<8;
        msg[i-1] |= (msg[i] & 0xff);
    }
    msg[7] &= ~0xff;
    msg[7] |= 7<<8;
    msg[7] |= val;
}
void setup_bb(void) {
    // Enable RCC to GPIOB
    RCC->AHBENR |= RCC_AHBENR_GPIOBEN;
    // Clear PB12,13,15
    GPIOB->MODER &= ~0xCF000000; // Clear PB0-10
    // GPIOB PB12,13,15 Output
    GPIOB->MODER |= 0x45000000;
    // NSS high SCK low
    GPIOB->ODR |= 1<<12;
    GPIOB->ODR &= ~(1<<13);
}

void small_delay(void) {
    //nano_wait(5000000);
}

void bb_write_bit(int val) {
    if (val == 0) {
        // Set MOSI low
        GPIOB->ODR &= ~(1<<15);
    } else {
        // Set MOSI high
        GPIOB->ODR |= 1<<15;
    }
    small_delay();
    GPIOB->ODR |= 1<<13; // Set SCK High
    small_delay();
    GPIOB->ODR &= ~(1<<13); // Set SCK Low
}

void bb_write_halfword(int halfword) {
    GPIOB->ODR &= ~(1<<12); // Deassert NSS Pin;
    for (int i = 15; i >= 0; i--) {
        bb_write_bit(halfword & (1<<i)); // bit i
    }
    GPIOB->ODR |= 1<<12; // Assert NSS Pin;
}

void init_tim7(void) {
    RCC->APB1ENR |= 1<<5;
    TIM7->PSC = 4800-1;
    TIM7->ARR = 10-1;
    TIM7->DIER |= TIM_DIER_UIE;
    NVIC->ISER[0] = 1<<TIM7_IRQn;
    TIM7->CR1 |= TIM_CR1_CEN;
}

void TIM7_IRQHandler(void) {
    // Acknowledge Interrupt
    TIM7->SR &= ~TIM_SR_UIF;
    bb_write_halfword(msg[msg_index]);
    if (msg_index == 7) {
        msg_index = 0;
    } else {
        msg_index++;
    }
}


//===========================================================================
// 2.3 SPI DMA LED Array
//===========================================================================
void init_spi2(void) {
    // Enable RCC to SPI2
    RCC->APB1ENR |= RCC_APB1ENR_SPI2EN;
    // Enable GPIO Alternate function for PB12,13,15
    // Enable RCC to GPIOB
    RCC->AHBENR |= RCC_AHBENR_GPIOBEN;
    // Clear PB12,13,15
    GPIOB->MODER &= ~0xCF000000; // Clear PB0-10
    // GPIOB PB12,13,15 Alternate Function
    GPIOB->MODER |= 0x8a000000;
    // PB12: AF0
    GPIOB->AFR[1] &= ~(0xf << (4*(12-8)));
    GPIOB->AFR[1] |=   0x0 << (4*(12-8));
    // PB13: AF0
    GPIOB->AFR[1] &= ~(0xf << (4*(13-8)));
    GPIOB->AFR[1] |=   0x0 << (4*(13-8));
    // PB15: AF0
    GPIOB->AFR[1] &= ~(0xf << (4*(15-8)));
    GPIOB->AFR[1] |=   0x0 << (4*(15-8));
    SPI2->CR1 &= ~SPI_CR1_SPE; // Clear CR1_SPE
    SPI2->CR1 |= SPI_CR1_MSTR | SPI_CR1_BR; // Set baud rate 111
    // DS = 1111
    SPI2->CR2 = SPI_CR2_TXDMAEN | SPI_CR2_SSOE | SPI_CR2_NSSP | SPI_CR2_DS_3 | SPI_CR2_DS_2 | SPI_CR2_DS_1 | SPI_CR2_DS_0;
//    SPI2->CR2 |= SPI_CR2_SSOE | SPI_CR2_NSSP;
//    SPI2->CR1 |= SPI_CR2_TXDMAEN;
    SPI2->CR1 |= SPI_CR1_SPE;
}

void setup_dma(void) {
    // Enable RCC to DMA
    RCC->AHBENR |= RCC_AHBENR_DMAEN;
    DMA1_Channel5->CCR &= ~DMA_CCR_EN;  // Turn off DMA Channel before config
    DMA1_Channel5->CPAR = (uint32_t) &(SPI2->DR);
    DMA1_Channel5->CMAR = (uint32_t) msg;
    DMA1_Channel5->CNDTR = 8;
    DMA1_Channel5->CCR |= DMA_CCR_DIR;
    DMA1_Channel5->CCR |= DMA_CCR_MINC;
    DMA1_Channel5->CCR |= DMA_CCR_MSIZE_0;
    DMA1_Channel5->CCR |= DMA_CCR_PSIZE_0;
    DMA1_Channel5->CCR |= DMA_CCR_CIRC;
}

void enable_dma(void) {
    // Enable DMA
    DMA1_Channel5->CCR |= DMA_CCR_EN;
}


//===========================================================================
// 2.4 SPI OLED Display
//===========================================================================
void setup_spi1() {
    // Enable RCC to SPI2
    RCC->APB2ENR |= RCC_APB2ENR_SPI1EN;
    // Enable GPIO Alternate function for PB12,13,15
    // Enable RCC to GPIOB
    RCC->AHBENR |= RCC_AHBENR_GPIOAEN;
    // Clear PA5,6,7,15
    GPIOA->MODER &= ~0xc000fc00; // Clear  PA5,6,7,15
    // GPIOB PB12,13,15 Alternate Function
    GPIOA->MODER |= 0x8000a800;
//    // PB5: AF0
//    GPIOB->AFR[1] &= ~(0xf << (4*(5-8)));
//    GPIOB->AFR[1] |=   0x0 << (4*(5-8));
//    // PB6: AF0
//    GPIOB->AFR[1] &= ~(0xf << (4*(13-8)));
//    GPIOB->AFR[1] |=   0x0 << (4*(13-8));
//    // PB15: AF0
//    GPIOB->AFR[1] &= ~(0xf << (4*(15-8)));
//    GPIOB->AFR[1] |=   0x0 << (4*(15-8));
    SPI1->CR1 &= ~SPI_CR1_SPE; // Clear CR1_SPE
    SPI1->CR1 |= SPI_CR1_MSTR | SPI_CR1_BR; // Set baud rate 111
    // DS = 1111
    SPI1->CR2 = SPI_CR2_SSOE | SPI_CR2_NSSP | SPI_CR2_DS_3 | SPI_CR2_DS_0;
//    SPI2->CR2 |= SPI_CR2_SSOE | SPI_CR2_NSSP;
//    SPI2->CR1 |= SPI_CR2_TXDMAEN;
    SPI1->CR1 |= SPI_CR1_SPE;
}

void spi_cmd(unsigned int data) {
    while((SPI1->SR & SPI_SR_TXE) == 0);
    SPI1->DR = data;
}

void spi_data(unsigned int data) {
    while((SPI1->SR & SPI_SR_TXE) == 0);
    SPI1->DR = (0x200 | data);
}

void spi_init_oled() {
    nano_wait(1000000);
    spi_cmd(0x38);
    spi_cmd(0x08);
    spi_cmd(0x01);
    nano_wait(2000000);
    spi_cmd(0x06);
    spi_cmd(0x02);
    spi_cmd(0x0c);
}

void spi_display1(const char *string) {
    spi_cmd(0x02);
    for (int i = 0; i < strlen(string); i++) {
//        if (string[i] != "\0") {
            spi_data(string[i]);
//        }
    }
}

void spi_display2(const char *string) {
    spi_cmd(0xc0);
    for (int i = 0; i < strlen(string); i++) {
//        if (string[i] != "\0") {
            spi_data(string[i]);
//        }
    }
}


//===========================================================================
// Main and supporting functions
//===========================================================================

int main(void)
{
    msg[0] |= font['E'];
    msg[1] |= font['C'];
    msg[2] |= font['E'];
    msg[3] |= font[' '];
    msg[4] |= font['3'];
    msg[5] |= font['6'];
    msg[6] |= font['2'];
    msg[7] |= font[' '];

    // GPIO enable
    enable_ports();

    // setup keypad
    init_tim6();

    // 2.2 LED array Bit Bang
//    setup_bb();
//    init_tim7();

    // 2.3 LED array SPI
     setup_dma();
     enable_dma();
     init_spi2();

    // 2.4 SPI OLED
     setup_spi1();
     spi_init_oled();
     spi_display1("Hello again,");
     spi_display2(login);

    int key = 0;
    for(;;) {
        char key = get_keypress();
        append_display(font[key]);
    }
}

const char font[] = {
    0x01, 0x01, 0x01, 0x01, 0x01, 0x01, 0x01, 0x01,
    0x01, 0x01, 0x01, 0x01, 0x01, 0x01, 0x01, 0x01,
    0x01, 0x01, 0x01, 0x01, 0x01, 0x01, 0x01, 0x01,
    0x01, 0x01, 0x01, 0x01, 0x01, 0x01, 0x01, 0x01,
    0x00, // 32: space
    0x86, // 33: exclamation
    0x22, // 34: double quote
    0x76, // 35: octothorpe
    0x00, // dollar
    0x00, // percent
    0x00, // ampersand
    0x20, // 39: single quote
    0x39, // 40: open paren
    0x0f, // 41: close paren
    0x49, // 42: asterisk
    0x00, // plus
    0x10, // 44: comma
    0x40, // 45: minus
    0x80, // 46: period
    0x00, // slash
    // digits
    0x3f, 0x06, 0x5b, 0x4f, 0x66, 0x6d, 0x7d, 0x07, 0x7f, 0x67,
    // seven unknown
    0x01, 0x01, 0x01, 0x01, 0x01, 0x01, 0x01,
    // Uppercase
    0x77, 0x7c, 0x39, 0x5e, 0x79, 0x71, 0x6f, 0x76, 0x30, 0x1e, 0x00, 0x38, 0x00,
    0x37, 0x3f, 0x73, 0x7b, 0x31, 0x6d, 0x78, 0x3e, 0x00, 0x00, 0x00, 0x6e, 0x00,
    0x39, // 91: open square bracket
    0x00, // backslash
    0x0f, // 93: close square bracket
    0x00, // circumflex
    0x08, // 95: underscore
    0x20, // 96: backquote
    // Lowercase
    0x5f, 0x7c, 0x58, 0x5e, 0x79, 0x71, 0x6f, 0x74, 0x10, 0x0e, 0x00, 0x30, 0x00,
    0x54, 0x5c, 0x73, 0x7b, 0x50, 0x6d, 0x78, 0x1c, 0x00, 0x00, 0x00, 0x6e, 0x00
};

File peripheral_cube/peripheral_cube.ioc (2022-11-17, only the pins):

Mcu.UserName=STM32F091RCTx
PA13.Signal=SYS_SWDIO
PA14.Signal=SYS_SWCLK
PB3.Signal=SPI1_SCK
PB4.Signal=SPI1_MISO
PB5.Signal=SPI1_MOSI
PB8.Signal=GPIO_Output
PF0-OSC_IN.Signal=I2C1_SDA
PF1-OSC_OUT.Signal=I2C1_SCL

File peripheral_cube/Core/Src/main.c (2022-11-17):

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
/* Includes ------------------------------------------------------------------*/
#include "main.h"

/* USER CODE BEGIN Includes */
#include "lcd.h"
#include "stm32f0xx_hal_def.h"
#include "stm32f0xx_hal_gpio.h"
#include "stm32f0xx_hal_spi.h"
/* USER CODE END Includes */

I2C_HandleTypeDef hi2c1;

SPI_HandleTypeDef hspi1;

TIM_HandleTypeDef htim7;

/* USER CODE BEGIN PV */
uint8_t aTxBuffer[20];
/* USER CODE END PV */

void SystemClock_Config(void);
static void MX_GPIO_Init(void);
static void MX_I2C1_Init(void);
static void MX_SPI1_Init(void);
static void MX_TIM7_Init(void);
/**
  * @brief  The application entry point.
  * @retval int
  */
int main(void)
{
  /* MCU Configuration--------------------------------------------------------*/

  /* Reset of all peripherals, Initializes the Flash interface and the Systick. */
  HAL_Init();

  /* Configure the system clock */
  SystemClock_Config();

  /* Initialize all configured peripherals */
//  MX_GPIO_Init();
//  MX_I2C1_Init();
//  MX_SPI1_Init();
//  MX_TIM7_Init();
  /* USER CODE BEGIN 2 */
  initEXTI();
  LCD_Setup();
  LCD_Clear(BLACK);
  char *str = "!dlroW, olleH";
  LCD_DrawString(20, 20, BLACK, WHITE, str, 14, 0);

  /* USER CODE END 2 */

  /* Infinite loop */
  /* USER CODE BEGIN WHILE */
  while (1) {
    /* USER CODE END WHILE */

    /* USER CODE BEGIN 3 */
  }
  /* USER CODE END 3 */
}

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
/* USER CODE BEGIN 4 */
void initEXTI(void) {
  RCC->APB2ENR |= RCC_APB2ENR_SYSCFGCOMPEN;
  RCC->AHBENR |= RCC_AHBENR_GPIOAEN;
  // Associate PA0 with exti 0
  SYSCFG->EXTICR[0] &= ~(15);
  GPIOA->MODER &= ~(3);
  GPIOA->PUPDR |= 2;
  EXTI->RTSR |= 1;
  EXTI->IMR |= 1;
  NVIC_EnableIRQ(EXTI0_1_IRQn);
  NVIC_SetPriority(EXTI0_1_IRQn, 3);
}

/* USER CODE END 4 */
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


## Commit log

2022-09-10 Updated .gitignore for STM32CubeIDE
2022-09-10 Added I2C_Test project with i2c3 and otg init
2022-09-10 Added GPIO EXTI0 interrupt on Button0 to toggle LED4
2022-09-10 Added I2C send test packet on I2C3
2022-09-19 Update main.c
    Fix mistake
    [main.c]
2022-09-19 Update main.c
    Fixed some issues
    [main.c]
2022-09-19 code used in slides, I think this would also work however this is configuring the EEPROM and GPIO chip as master and slave, so if we go with this one we will need to rework it to just be the slave
    [main.c]
2022-09-20 Update f4 code to tell f0 to toggle led
2022-09-26 updated gitignore for kicad
2022-09-26 Added main-keyboard kicad project
    [main-keyboard-pcb.kicad_pcb, main-keyboard-pcb.kicad_sch]
2022-09-26 Added footprints for buck converter
2022-09-26 Added buck converter to schematic
    [main-keyboard-pcb.kicad_sch]
2022-09-27 Added buck converter footprints
    [main-keyboard-pcb.kicad_sch]
2022-09-27 added parts and lcd pcb
    [7427920415.stp, BAT_60B_E6327.stp, CHV1206AJW-104ELF.stp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]
2022-09-27 added pcb for lcd
    [BAT60JFILM.stp, LCDPCB.kicad_pcb, LCDPCB.kicad_sch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]
2022-09-27 added midterm review
    [LCDPCB.kicad_sch]
2022-09-28 updated with pins
    [FSM2JSMAATR.stp, LCDPCB.kicad_pcb, LCDPCB.kicad_sch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]
2022-10-03 display done
    [C1210C822K2RACAUTO.stp, LCDPCB.kicad_pcb, LCDPCB.kicad_sch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]
2022-10-03 design mk 2
    [LCDPCB.kicad_pcb]
2022-10-03 Added Arisu keswitch matrix
    [main-keyboard-pcb.kicad_pcb, main-keyboard-pcb.kicad_sch, matrix.kicad_sch]
2022-10-03 Removed old traces and routing
    [main-keyboard-pcb.kicad_pcb, main-keyboard-pcb.kicad_sch]
2022-10-03 Updated diodes
    [main-keyboard-pcb.kicad_pcb, main-keyboard-pcb.kicad_sch]
2022-10-04 fixed 1kR
    [ERJ-UP3D1001V.stp, LCDPCB.kicad_pcb, LCDPCB.kicad_sch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]
2022-10-04 Completed footprint library for main-keyboard and rough part placement
    [main-keyboard-pcb.kicad_pcb, main-keyboard-pcb.kicad_sch]
2022-10-04 Initial routing for stm32f4 and keyswitch matrix
    [main-keyboard-pcb.kicad_pcb]
2022-10-04 Routed keyswitch matrix to microcontroller
    [main-keyboard-pcb.kicad_pcb]
2022-10-04 Finished initial PCB design, spacing fixes needed
    [main-keyboard-pcb.kicad_sch]
2022-10-04 Updated buck converter design to webench recommendation and updated caps to 0805
    [main-keyboard-pcb.kicad_sch]
2022-10-05 v2 lcd pcb
    [0805J0630104MXT.stp, C0805C226K7PAC7800.stp, C1210C822K2RACAUTO.stp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]
2022-10-05 Moved over components to 0805 packaging, updated buck converter, added side hotplug connector
    [main-keyboard-pcb.kicad_sch]
2022-10-05 Added page info to pcb
2022-10-05 updated pcb text
2022-10-05 added an edit, 3.3V to decoupling capacitor
    [LCDPCB.kicad_pcb, LCDPCB.kicad_sch]
2022-10-05 Added labels to boot0 switch and debug vias
2022-10-06 added thermal relief, made 5V routes wider
    [LCDPCB.kicad_pcb, LCDPCB.kicad_sch]
2022-10-07 moved cols to GPIOE and rows to GPIOA
    [main-keyboard-pcb.kicad_sch]
2022-10-07 added thermal reliefs
    [LCDPCB.kicad_pcb, LCDPCB.kicad_sch, TMK212BBJ106MG-T.stp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]
2022-10-07 updated back silkscreens
    [main-keyboard-pcb.kicad_sch]
2022-10-09 pressed b
    [LCDPCB.kicad_pcb]
2022-10-10 do you love me now dad?
    [LCDPCB.kicad_pcb, LCDPCB.kicad_sch]
2022-10-12 remove via from pad v2
    [LCDPCB.kicad_pcb]
2022-10-15 Replaced Boot0 with reset sw and created exclusion zone on oscillator
    [main-keyboard-pcb.kicad_sch]
2022-10-15 Updated design constraint copper to edge to 0.03mm
2022-10-16 free of errors
    [LCDPCB.kicad_pcb]
2022-10-16 minor cosmetic change
    [LCDPCB.kicad_pcb]
2022-10-18 Fixed osc pads and added pull down resistors
    [main-keyboard-pcb-B_Cu.gbr, main-keyboard-pcb-B_Mask.gbr, main-keyboard-pcb-B_Paste.gbr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]
2022-10-18 added series resistors
    [main-keyboard-pcb-B_Cu.gbr, main-keyboard-pcb-B_Mask.gbr, main-keyboard-pcb-B_Paste.gbr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]
2022-10-18 redid gerber
    [LCDPCB-B_Cu.gbr, LCDPCB-B_Mask.gbr, LCDPCB-B_Paste.gbr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]
2022-10-18 Added courtyards for hotswap sockets
    [main-keyboard-pcb-B_Cu.gbr, main-keyboard-pcb-B_Mask.gbr, main-keyboard-pcb-B_Paste.gbr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]
2022-10-18 move a via
    [LCDPCB-B_Cu.gbr, LCDPCB-B_Mask.gbr, LCDPCB-B_Paste.gbr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]
2022-10-18 Fixed differences between sch and pcb
    [main-keyboard-pcb-B_Cu.gbr, main-keyboard-pcb-B_Mask.gbr, main-keyboard-pcb-B_Paste.gbr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]
2022-10-18 Fixed via in pad
    [main-keyboard-pcb-B_Cu.gbr, main-keyboard-pcb-B_Mask.gbr, main-keyboard-pcb-B_Paste.gbr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]
2022-10-18 Fixed via in pads again
    [main-keyboard-pcb-B_Cu.gbr, main-keyboard-pcb-B_Mask.gbr, main-keyboard-pcb-B_Paste.gbr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]
2022-10-18 Fixed trace change error
    [main-keyboard-pcb-B_Cu.gbr, main-keyboard-pcb-B_Mask.gbr, main-keyboard-pcb-B_Paste.gbr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]
2022-10-19 added logo
    [LCDPCB-B_Cu.gbr, LCDPCB-B_Mask.gbr, LCDPCB-B_Paste.gbr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]
2022-10-19 added drill to gerber
    [LCDPCB-B_Cu.gbr, LCDPCB-B_Mask.gbr, LCDPCB-B_Paste.gbr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]
2022-10-19 added drill to main
    [main-keyboard-pcb-B_Cu.gbr, main-keyboard-pcb-B_Mask.gbr, main-keyboard-pcb-B_Paste.gbr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]
2022-10-20 drill lcd
    [LCDPCB-NPTH.drl, LCDPCB-PTH.drl]
2022-10-20 main drill
    [main-keyboard-pcb-NPTH.drl, main-keyboard-pcb-PTH.drl]
2022-11-01 Fix for new i2c controller
    [main.c]
2022-11-05 Fix SysTick / EXTI interrupt level conflict and send the right keycode
    [i2c_test.ioc, main.c]
2022-11-15 submodule casing files
    [LCDPCB.kicad_pcb, LCDPCB.kicad_sch, Submodule-Bottom.dwg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]
2022-11-17 normal peripheral
    [Submodule-Bottom.dwg, Submodule-Top.dwg]
2022-11-17 renamed pa13 and 14
    [LCDPCB.kicad_pcb, LCDPCB.kicad_sch]
2022-11-17 Added cube spi
2022-11-17 Push 'ported' lcd driver
2022-11-17 Configure pin B8 as output
2022-11-17 Hello World working on SPI
2022-12-01 new case
    [Main Keyboard.dwg, Main Keyboard.dxf, Submodule-Bottom.dwg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]

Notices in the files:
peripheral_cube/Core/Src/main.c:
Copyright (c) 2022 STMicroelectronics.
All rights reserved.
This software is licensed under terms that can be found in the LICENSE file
